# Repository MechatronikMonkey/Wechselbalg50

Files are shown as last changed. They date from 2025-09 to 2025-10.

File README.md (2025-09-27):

# Wechselbalg 50 (WB50)
Wechselbalg 50 is a 50‑watt tube guitar amplifier built entirely on a PCB. It combines classic British crunch with a modern high‑gain voice, switchable by relay. The name “Wechselbalg” (changeling) nods to the two distinct characters living in one chassis.

> Tagline (working): “Two voices, one heart of iron.”

## Highlights
- Two switchable voicings via relay (Classic ↔ Beast)
- Cascaded 12AX7 preamp with bright peakers
- Cathode follower into a classic T/M/B tone stack
 - Serial FX loop (always active; not bypassable); dual master volumes (post‑loop, RL3 selects)
- Long‑tail‑pair PI → 2× EL34 push‑pull power stage
- Classic British NFB with Presence & Thump (Resonance/Depth)
- Fixed, trimmable bias; regulated 12‑V rail (7812) for relays/loop
- Layout goals: star‑like grounding, short grid leads, disciplined heater routing, decoupled HT nodes

## Circuit overview
1) Input and V1: high‑value grid leak + grid stopper, cathode bypass options for British mid focus.  
2) Voicing section: relay switches additional gain/treble‑peaking networks for the Beast mode.  
3) Cathode follower → passive T/M/B tone stack for low‑impedance drive.  
4) FX loop: buffered send/return; always in circuit (no bypass); two post‑loop master volumes (Rhythm/Lead) with relay selection.  
5) Phase inverter: long‑tail‑pair (12AX7) with balanced plate loads.  
6) Power stage: 2× EL34 fixed‑bias push‑pull; screen resistors; coupling caps per side.  
7) Feedback shaping: Presence and Resonance inside the negative feedback leg from the output transformer secondary.  
8) Power supply: bridge rectifier, choke‑assisted filtering and stepped B+ distribution; regulated 12 V for control circuitry.

## Channel switching and controls
- Channel toggle (front) or footswitch (“SW.” jack) drives a common control line that actuates multiple relays:
	- RL1: preamp voicing (Plexi ↔ BE)
	- RL2: gain pot routing (Gain 1 ↔ Gain 2)
	- RL3: master selection (Volume 1 ↔ Volume 2, both post‑loop)
- The “SW.” jack is a latching footswitch input (no audio). With a plug inserted, the footswitch takes over; without it, the front‑panel CHANNEL mini‑toggle controls the state.
- Result: two distinct channels with their own Gain and Master settings while keeping the FX loop operating at a stable level.
 - Rear control: Thump (Resonance/Depth) shapes low‑frequency feedback for tighter vs. bigger low‑end feel.

## Safety
This project involves lethal voltages up to ~500 V. Only qualified persons should build or service it. Always discharge filter caps, use an isolation transformer, work one‑handed where possible, and wear eye protection.

## Scope & status
This repository aims at a reproducible PCB implementation of a classic small‑box‑style topology (without using protected brand names).  
Planned artifacts: schematic capture, PCB layout, BOM, bring‑up checklist and measurement notes.

## Naming
“Wechselbalg” = changeling/shapeshifter – a subtle hint at the two switchable voices. Short code: WB50.

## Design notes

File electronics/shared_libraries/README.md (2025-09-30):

# Gemeinsame Bibliotheken für Wechselbalg50

Dieser Ordner enthält gemeinsame Bibliotheken für die Projekte im Wechselbalg50-Repository.

## Struktur

- `symbols/`: Enthält Symbol-Bibliotheken (.kicad_sym)
- `footprints/`: Enthält Footprint-Bibliotheken (.pretty)
- `3dmodels/`: Enthält 3D-Modelle für die Footprints

## Verwendung

Die Projekte im Repository sind bereits so konfiguriert, dass sie auf diese gemeinsamen Bibliotheken zugreifen.
Die Pfade in den Bibliothekstabellen (`sym-lib-table` und `fp-lib-table`) verwenden den relativen Pfad `${KIPRJMOD}/../shared_libraries/...`.

## Hinzufügen neuer Symbole/Footprints

Wenn du neue Symbole oder Footprints erstellen möchtest, die in mehreren Projekten verwendet werden sollen:

1. Öffne KiCad und den Symbol- oder Footprint-Editor
2. Stelle sicher, dass du auf die gemeinsame Bibliothek als aktive Bibliothek eingestellt hast
3. Erstelle dein neues Symbol/Footprint und speichere es in der gemeinsamen Bibliothek
4. Es wird dann automatisch in allen Projekten verfügbar sein, die auf die gemeinsame Bibliothek verweisen

## 3D-Modelle

Für 3D-Modelle sollte der Pfad in den Footprint-Eigenschaften entsprechend angepasst werden. 
Verwende `${KIPRJMOD}/../shared_libraries/3dmodels/...` anstelle von lokalen Pfaden.

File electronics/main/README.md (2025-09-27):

# WB50 KiCad Projektstruktur

Dieses Verzeichnis enthält das komplette KiCad-Projekt inkl. lokaler Bibliotheken, Teilschaltpläne, PCB-Hilfsdateien und Fertigungs-/Montageordner.

## Struktur
- libraries/
  - symbols/: Projekt‑Symbolbibliothek `wb50_symbols.kicad_sym`
  - footprints/: Projekt‑Footprints in `wb50_footprints.pretty/`
  - 3dmodels/: 3D‑Modelle (optional)
- schematics/: Teilschaltpläne, die später als Hierarchieblätter in `wb50.kicad_sch` eingebunden werden
- pcb/: DXF‑Hilfsdateien (Board‑Outline, Keepouts, Front/Rear‑Panel‑Guides)
- fabrication/: Gerber/Bohrdaten, Fab‑Notizen, Stückliste und Pick&Place
- simulation/spice/: SPICE‑Testbench und Model‑Hinweise

## Erste Schritte (Front‑/Rear‑Panel zuerst)
1) Symbole & Footprints erstellen/zuweisen
   - Externe Bedienelemente (Potenziometer, Schalter, Klinken, Netz‑/Standby‑Schalter, LED) als Symbole in `wb50_symbols.kicad_sym` pflegen.
   - Passende Footprints in `wb50_footprints.pretty/` ablegen oder Standardbibliotheken verwenden.
2) Teilschaltpläne befüllen
   - In `schematics/` liegen Platzhalter für Preamp, Voicing‑Relays, Tone‑Stack, FX‑Loop, Masters, PI, Power‑Amp, NFB‑Shaping, Power‑Supply, Control‑Power.
   - Externe Bedienelemente zunächst sauber im Schaltplan anlegen (mit eindeutigen Referenzen und Netz‑Namen).
3) PCB‑Vormontage der Front/Rear‑Elemente
   - Im PCB‑Editor die Footprints der externen Bedienelemente zuerst entsprechend der Front/Rear‑Panel‑Mechanik platzieren.
   - DXF‑Hilfsgeometrie in `pcb/` importieren (Panel‑Bohrungen/Abstände), um Positionen zu verifizieren.
4) Verdrahtung/Netze nachziehen
   - Danach restliche Baugruppen platzieren, sensible Netze kurz halten (Grids, CF→Tonestack), sternförmige Masseführung beachten.

Tipp: In der `sym-lib-table` und `fp-lib-table` sind die lokalen Bibliotheken bereits auf `${KIPRJMOD}` referenziert.

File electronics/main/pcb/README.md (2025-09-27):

DXF‑Hilfsdateien (Board‑Outline, Keepouts, Panel‑Bohrungen) können hier abgelegt und in den PCB‑Editor importiert werden.

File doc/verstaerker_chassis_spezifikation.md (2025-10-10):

# Verstärker-Chassis Wechselbalg50 - Spezifikation

## Bestellung
**Datum**: 10. Oktober 2025
**Lieferant**: Tube-Town
**Artikel**: TTC Headshell British #15 - Open Frame
**Art.Nr.**: ttc-hd-br15
**Lieferzeit**: ca. 12-15 Wochen

## Abmessungen
- **A (Breite)**: 550 mm
- **B (Höhe)**: 220 mm  
- **C (Tiefe)**: 240 mm
- **Gewicht**: 8 kg
- **Konstruktion**: Open Frame (offen für optimale Belüftung)

## Materialien und Ausstattung

### Oberflächenfinish
- **Tolex**: [to-tt-ivo] Tube-Town Elfenbein / Ivory
- **Zierpiping**: Gold (abgestimmt auf Lautsprecherbox-Keder)

### Mechanische Ausstattung
- **Ecken**: [pe-c1824k] Metallecken schwarz 2-schenkelig
- **Griff**: [fe099-0943] Fender® Vintage Dogbone schwarz

## Design-Koordination

### **Perfektes Matching mit Lautsprecherbox:**
```
                   VERSTÄRKER         LAUTSPRECHERBOX
Abmessungen:       550x220x240mm      550x500x260mm
Tolex:             Ivory              Ivory            ✅
Ecken:             Schwarz 2-schenkelig Schwarz 2-schenkelig ✅  
Griff:             Fender Dogbone      Fender Dogbone   ✅
Akzente:           Gold Piping         Gold Keder       ✅
```

### **Stapelbare Konfiguration:**
- **Identische Breite**: 550mm - perfekt stapelbar
- **Harmonische Proportionen**: Head/Cabinet Verhältnis ~1:2,3
- **Einheitliches Design**: Komplettes Ivory/Schwarz/Gold Schema

## Technische Eigenschaften
- **Open Frame Konstruktion**: Optimale Wärmeableitung für Röhren
- **British Style**: Klassisches Marshall-inspiriertes Design
- **Robuste Bauweise**: Metallecken für Touring-Tauglichkeit
- **Kompakte Abmessungen**: Transportfreundlich bei voller Funktionalität

## Elektronik-Kompatibilität
**Ausgelegt für**:
- 50W Röhrenverstärker
- EL34 Push-Pull Endstufe
- 2x 12AX7 Vorstufe
- Transformatoren bis 3kg (Power + Output)
- Hammond 193H Drossel

## Kosten
- **Warenwert**: 300,79 €
- **Versand**: 8,45 €
- **MwSt**: 49,37 €
- **Gesamtsumme**: 309,24 €

## Notizen
- Professionelle TTC Fertigung (12-15 Wochen)
- Perfekt abgestimmt auf TTC 1x12" Lautsprecherbox
- Hochwertige Materialien im vintage Fender-Stil
- Open Frame für optimale Röhren-Kühlung
- Komplettes Set mit einheitlichem Design-Schema

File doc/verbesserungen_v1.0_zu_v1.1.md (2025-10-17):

# Verbesserungen von Version 1.0 zu Version 1.1

**Datum:** 15. Oktober 2025

## Übersicht
Dieses Dokument beschreibt die notwendigen Verbesserungen und Änderungen zwischen Version 1.0 und Version 1.1 des Wechselbalg50 Röhrenverstärkers.

---

## 1. Kathoden-Heizung Spannungsdifferenz

### Problem
Die Spannungsdifferenz zwischen Kathode und Heizung darf gemäß Röhrenspezifikation maximal 100V betragen. Bei der aktuellen Schaltung V1.0 besteht die Gefahr, dass die Kathode der Tone-Stack-Vorstufe auf ca. 160V ansteigt, was die zulässige Differenz überschreitet.

### Geplante Maßnahmen

#### 1.1 Überprüfung aller Kathodenspannungen
- [ ] Messung aller Kathodenspannungen im Betrieb
- [ ] Dokumentation der gemessenen Werte
- [ ] Vergleich mit zulässigen Maximalwerten der verwendeten Röhren
- [ ] Besondere Aufmerksamkeit auf Tone-Stack-Vorstufe

#### 1.2 Heater Voltage Elevation (falls erforderlich)
**Bedingung:** Wenn Kathodenspannung > 90V

**Maßnahme:** Heizspannungsanhebung um 75V

- [ ] Implementierung einer Heater Voltage Elevation Schaltung
- [ ] Anhebung der Heizspannung um 75V
- [ ] Neuberechnung der Kathode-Heizung-Differenz
- [ ] Verifizierung: Differenz < 100V
- [ ] Anpassung des Schaltplans (Schematic Update)
- [ ] Update der PCB-Layout falls erforderlich

#### 1.3 Umstellung auf 5V Relais-Steuerung (falls 1.2 implementiert wird)
**Bedingung:** Wenn Heater Voltage Elevation implementiert wird

**Hintergrund:** Durch die Heizspannungsanhebung wird eine separate 5V Versorgung für die Relais-Steuerung erforderlich.

**Maßnahme:** Implementierung 5V Versorgung und Umstellung auf 5V Relais

- [ ] Recherche und Auswahl geeigneter 5V Relais für Kanalumschaltung
- [ ] 5V Wicklung vom Transformator nutzen (falls vorhanden) oder separate Lösung
- [ ] Brückengleichrichter für 5V AC Wicklung
- [ ] LDO Spannungsregler für 5,0V Regulierung (analog zur 12V Versorgung)
- [ ] Schaltplan Update: 5V Versorgungssektion
- [ ] Schaltplan Update: Relais-Ansteuerung auf 5V umstellen
- [ ] PCB Update: 5V Relais Footprints
- [ ] BOM Update: 5V Relais, LDO für 5V, Brückengleichrichter

### Erwartetes Ergebnis
- Kathodenspannung Tone-Stack: ~160V (gemessen)
- Heizspannung (elevated): +75V
- Resultierende Differenz: ~85V ✓ (< 100V Limit)

---

## 2. Thermisches Management / PCB-Layout

### Problem
Die Wärmeentwicklung der Röhren kann zu erhöhten Temperaturen auf der PCB führen, was die Lebensdauer und Zuverlässigkeit der Bauteile beeinträchtigen kann.

### Geplante Maßnahmen

#### 2.1 Temperaturmessung und Analyse
- [ ] Temperaturmessung auf der PCB im Betrieb (verschiedene Lastbedingungen)
- [ ] Identifikation von Hotspots
- [ ] Messung der Bauteiltemperaturen in Röhrennähe
- [ ] Dokumentation der Temperaturen (Idle, Normal, Vollast)
- [ ] Vergleich mit maximalen Betriebstemperaturen der Bauteile

#### 2.2 PCB-Layout Optimierung (falls erforderlich)
**Bedingung:** Wenn Bauteiltemperaturen kritische Werte erreichen

**Maßnahme:** Vergrößerung des Abstands zwischen Röhrensockeln und temperaturkritischen Bauteilen

- [ ] Analyse: Welche Bauteile sind besonders temperaturempfindlich?
- [ ] PCB-Layout Revision: Bauteile weiter von Röhrensockeln positionieren
- [ ] Berücksichtigung thermischer Konvektion (heiße Luft steigt auf)
- [ ] Ggf. Verwendung von Bauteilen mit höherer Temperaturklasse
- [ ] Ggf. zusätzliche Kühlung/Belüftung in Betracht ziehen
- [ ] PCB Update für Version 1.1
- [ ] Prototyp-Test mit Temperaturmessung zur Validierung

### Erwartetes Ergebnis
- Alle Bauteile arbeiten innerhalb ihrer spezifizierten Temperaturbereiche
- Erhöhte Zuverlässigkeit und Lebensdauer
- Reduziertes Risiko von thermisch bedingten Ausfällen

---

## Weitere geplante Verbesserungen
_(Hier können weitere Punkte ergänzt werden)_

---

## Status
- **Version 1.0:** Aktuell in Entwicklung
- **Version 1.1:** Geplant
- **Hauptgrund für Update:** Einhaltung Kathode-Heizung Spannungsdifferenz

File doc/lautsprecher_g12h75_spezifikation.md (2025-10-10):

# Lautsprecher-Spezifikation: Celestion G12H-75 Creamback

## Produktdetails
**Hersteller**: Celestion
**Modell**: G12H-75 Creamback
**Impedanz**: 8Ω
**Datum**: 10. Oktober 2025

## Technische Daten
- **Belastbarkeit**: 75W RMS
- **Impedanz**: 8Ω
- **Magnet**: Keramik
- **Durchmesser**: 12" (305mm)
- **Resonanzfrequenz**: ~75Hz
- **Frequenzgang**: 70Hz - 5kHz
- **Empfindlichkeit**: ~96dB

## Sound-Charakteristik

### **Frequenzverhalten:**
- **Bass**: Straff und kontrolliert
- **Mitten**: Sehr präsent und aggressiv (2-4kHz Peak)
- **Höhen**: Scharf und durchsetzungsfähig
- **Breakup**: Musikalisch bei höheren Pegeln

### **Klangcharakter:**
- Klassischer 70er Hard Rock Sound
- Aggressive, schneidende Mitten
- Perfekt für Marshall JCM800/Plexi Style
- Hervorragende Durchsetzungsfähigkeit
- Modern verbesserte Version der Heritage Serie

## Kompatibilität mit Wechselbalg50

### **Perfektes Matching:**
```
Verstärker: 50W EL34 Push-Pull
Lautsprecher: 75W Belastbarkeit
Sicherheitsfaktor: 1,5x ✅

8Ω Impedanz:
- Optimale Anpassung für NFB-Umschaltung
- Straffe Bassansprache
- Moderne Charakteristik
```

### **Sound-Modi Kompatibilität:**
```
Classic Mode (weniger NFB):
- Warmer, vintage Marshall Sound
- Natürliches Röhren-Breakup
- Musikalische Kompression

Beast Mode (mehr NFB):  
- Aggressive, schneidende Mitten
- Straffe, kontrollierte Bässe
- Modern High-Gain Character
```

## Gehäuse-Integration

### **TTC 1x12" Box (550x500x260mm):**
- **Montage**: Standard 12" Ausschnitt (310mm)
- **Tiefe**: Ausreichend Platz (260mm Gehäuse)
- **Dämpfung**: Empfohlene Innenauskleidung mit 25mm PU-Schaum
- **Port**: Geschlossen oder Flex-Back je nach gewünschtem Sound

## Kostenaufstellung
- **Lautsprecher**: ~165€ (geschätzt)
- **Versand**: ~10-15€
- **Gesamtkosten**: ~175-180€

## Bezugsquellen (Empfehlung)
1. **Thomann**: Zuverlässig, guter Service
2. **Music Store**: Oft günstige Preise
3. **Amazon**: Schnelle Lieferung
4. **Tube-Town**: Passend zu restlicher Bestellung

## Sound-Erwartung

### **Perfekt für:**
- Hard Rock / Classic Rock
- Marshall-Style Crunch Sounds  
- Aggressive Lead-Sounds
- Durchsetzungsfähige Rhythmus-Gitarre

### **Weniger geeignet für:**
- Sehr cleane Jazz-Sounds
- Extreme High-Gain Metal (dafür ist er aber zu vintage)
- Sehr warme, runde Sounds (dafür G12M-65 wählen)

## Fazit
Der G12H-75 Creamback 8Ω ist die perfekte Ergänzung zum Wechselbalg50. Die Kombination aus klassischem 70er Marshall Character und modernen Verbesserungen macht ihn ideal für die zwei Persönlichkeiten (Classic ↔ Beast) des Verstärkers.

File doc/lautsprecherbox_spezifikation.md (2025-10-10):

# Lautsprecherbox Wechselbalg50 - Spezifikation

## Bestellung
**Datum**: 10. Oktober 2025
**Lieferant**: Tube-Town
**Artikel**: TTC 1X American Custom Shop
**Art.Nr.**: ttc-1XAM
**Lieferzeit**: ca. 12-15 Wochen

## Abmessungen
- **A (Breite)**: 550 mm
- **B (Höhe)**: 500 mm  
- **C (Tiefe)**: 260 mm
- **Gewicht**: 25 kg
- **Konfiguration**: 1x12" Lautsprecher

## Materialien und Ausstattung

### Oberflächenfinish
- **Tolex**: [to-tt-ivo] Tube-Town Elfenbein / Ivory
- **Bespannung**: [gc-ma-651] British schwarz, FRET00026
- **Keder**: Dick Gold, 4.8 x 9.1 mm

### Mechanische Ausstattung
- **Rückwand**: Flex Back / 3-geteilte Rückwand (abnehmbar für Sound-Variation)
- **Ecken**: [pe-c1819k] Fender® Stil schwarz, 2-schenkelig
- **Griff**: [fe099-0943] Fender® Vintage Dogbone schwarz
- **Front**: XL Front, schräge Schallwand
- **TT Logo**: kein Logo
- **Kabelsatz**: ohne Kabelsatz (wird separat beschafft)
- **Griffschale seitlich**: Nein
- **Steckrollen**: Nein

## Technische Eigenschaften
- **Innenvolumen**: ~53 Liter (geschlossen)
- **Konstruktion**: Geschlossen mit abnehmbarer 3-geteilter Rückwand
- **Sound-Charakteristik**: 
  - Geschlossen: Straffer, präziser Bass
  - Teilweise/ganz offen: Luftiger, vintage Sound
- **Kompatibilität**: Optimiert für 50W Röhrenverstärker mit EL34 Endstufe

## Geplanter Lautsprecher
**Lautsprecher**: Celestion G12H-75 Creamback 8Ω
- **Leistung**: 75W RMS (ausreichend für 50W Verstärker)
- **Impedanz**: 8Ω (optimiert für NFB-Umschaltung)
- **Charakteristik**: Aggressive Mitten, durchsetzungsfähig, perfekt für Marshall-Style
- **Sound**: Klassischer 70er Hard Rock Character mit modernen Verbesserungen

## Kosten
- **Warenwert**: 394,79 €
- **Versand**: 23,80 €
- **MwSt**: 66,83 €
- **Gesamtsumme**: 418,59 €

## Notizen
- Professionelle Fertigung durch Tube-Town
- Hochwertige Materialien im Fender-Stil
- Flexible Rückwand ermöglicht Sound-Anpassung
- Perfekt abgestimmt auf den Wechselbalg50 Röhrenverstärker
- Kompakte Abmessungen bei optimaler Klangqualität

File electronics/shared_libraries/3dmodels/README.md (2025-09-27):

3D‑Modelle (STEP/VRML) für Visualisierung und Mechanik‑Checks.

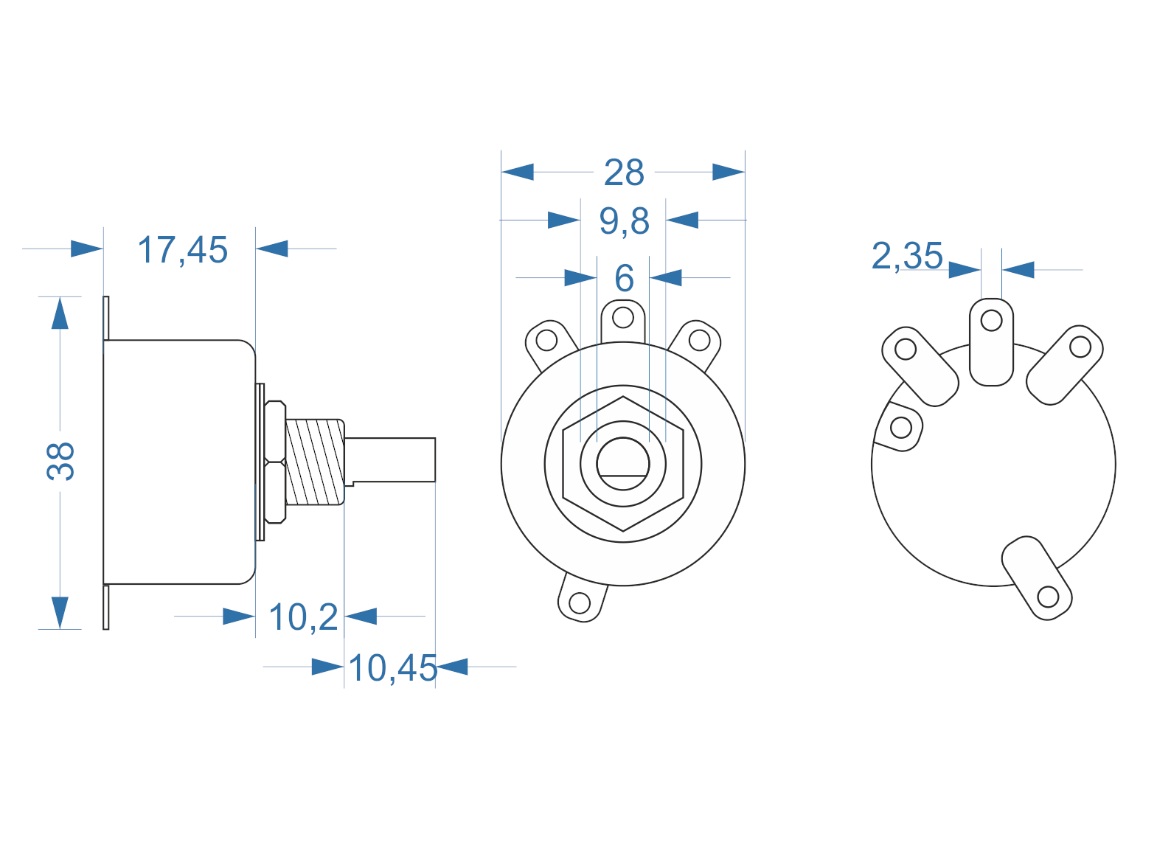
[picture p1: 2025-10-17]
doc/datasheets/imedanceSelector.png

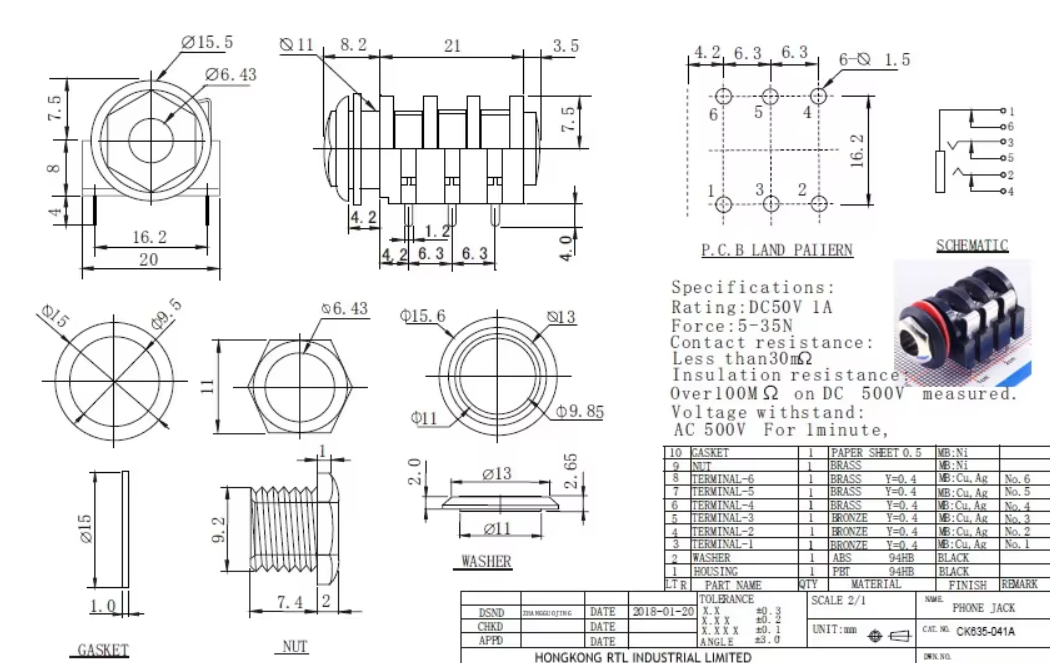
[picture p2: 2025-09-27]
doc/datasheets/trs_jack_6_35mm_dimensions.png

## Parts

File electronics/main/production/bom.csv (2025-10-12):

Designator | Footprint | Quantity | Value | LCSC Part #
AC-IN1, AC-IN2, AC-IN3, AC-IN4, AC-IN5, AUDIO-A1, AUDIO-B1, AUDIO-FROM-FX1, AUDIO-FROM-FX2, AUDIO-TO-FX1, AUDIO-TO-FX2, GND-AUD1, HV-B1, HV-OT1, HV-OT2, THUMP1, THUMP2 | TestPoint_THTPad_D3.0mm_Drill1.5mm | 17 | 1
AC-IN6, AC-IN7, AC-IN8 | TestPoint_THTPad_D4.0mm_Drill2.0mm | 3 | 1
AIR1, AIR10, AIR11, AIR12, AIR13, AIR14, AIR15, AIR16, AIR17, AIR18, AIR19, AIR2, AIR20, AIR21, AIR22, AIR3, AIR4, AIR5, AIR6, AIR7, AIR8, AIR9 | MountingHole_4.3mm_M4 | 22 | VentingHole
BIASA1, BIASB1, GND-MESS1 | TestPoint_Pad_D2.0mm | 3 | 1
C1 | CAP-TH_BD5.0-P2.00-D0.8-FD | 1 | 33uF 50V | C89792
C10, C8, C9 | CAP-TH_BD12.5-P5.00-D0.6-FD | 3 | 33uF 500V 5R5-ESR | C443401
C11, C12, C15 | CAP-TH_BD10.0-P5.00-D1.0-FD | 3 | 18uF 450V ±20% | C781269
C13, C14 | CAP-TH_BD6.3-P2.50-D1.0-FD | 2 | 10uf/100V | C2029
C2 | CAP-TH_BD16.0-P7.50-D1.2-FD | 1 | LKMI2501C682MF | C442803
C3, C4 | C0805 | 2 | CC0805KRX7R9BB104 | C49678
C5, C6 | CAP-TH_BD6.3-P2.50-D1.0-FD | 2 | 0,82uF 400V 20 % | C2029
C7 | CAP-TH_BD16.0-P7.50-D1.2-FD | 1 | 22uF_450V_16*20 | C10737
CHOKE1, CHOKE2 | TestPoint_THTPad_D2.5mm_Drill1.2mm | 2 | 1
D1, D2, D3, D4, D5, D6 | DO-41_BD2.4-L4.7-P8.70-D0.9-RD | 6 | UF4007_C960666 | C960666
J1 | WB50_Jack_TRS_6pin_16.2mm | 1 | IN
J2 | WB50_Jack_TRS_6pin_16.2mm | 1 | SW
J3 | WB50_Jack_TRS_6pin_16.2mm | 1 | OUT1
J4 | WB50_Jack_TRS_6pin_16.2mm | 1 | OUT2
J5 | WB50_Jack_TRS_6pin_16.2mm | 1 | Send
J6 | WB50_Jack_TRS_6pin_16.2mm | 1 | Return
MH3, MH4, MH5, MH6, MH7, MH8 | MountingHole_3.5mm_Pad_TopBottom | 6 | MountHole
N1, N2 | NetTie_0.5mm_2Pad | 2 | ~
R1, R15, R6 | RES-TH_BD3.0-L9.5-P13.50-D0.6 | 3 | 33k 500V 2W | C70845
R10, R11, R35, R36 | RES-TH_BD2.7-L6.2-P10.20-D0.4 | 4 | CR1/2WS-470K±5%-ST52 | C2857409
R12, R14, R20, R3, R5, R9 | RES-TH_BD4.5-L11.0-P15.00-D0.7 | 6 | CR1W-100K±5%-TT63 | C601829
R13 | RES-TH_BD4.0-L10.5-P14.50-D0.6 | 1 | 820R 350V 500mW | C167619
R16, R38, R42, R7 | RES-TH_BD4.5-L11.0-P15.00-D0.7 | 4 | CR1W-10M±5%-6T63 | C2897121
R17, R18, R2, R33 | RES-TH_BD2.4-L6.3-P10.30-D0.6 | 4 | 1Meg 500V 250mW | C1370556
R19, R25, R26, R27, R34 | RES-TH_BD5.5-L15.0-P19.00-D0.8 | 5 | CF3WS-10KΩ±5%_T | C120810
R21, R28 | RES-TH_BD2.7-L6.2-P10.20-D0.4 | 2 | CR1/4W-47K±5%-ST52 | C2896823
R22, R23 | RES-TH_BD2.4-L6.3-P10.30-D0.6 | 2 | CFR-25JT-52-1K5 | C1370569
R24 | RES-TH_BD6.0-L17.5-P21.50-D0.8 | 1 | MOF5WS-47Ω±5% | C121969
R29 | RES-TH_BD2.7-L6.2-P10.20-D0.4 | 1 | CR1/4W-15K±5%-OT52 | C2894565
R30, R31 | RES-TH_BD2.7-L6.2-P10.20-D0.4 | 2 | MF1/4W-1Ω±1%-ST26 | C2903254
R32, R39, R40, R44, U22, U27, U28, U4 | RES-TH_BD3.5-L9.0-P13.00-D0.5 | 8 | CR1/2W-220K±5%-XT52 | C2894491
R37 | RES-TH_BD2.3-L6.5-P10.50-D0.5 | 1 | CF1/4W-1_5KΩ±5%_T52 | C120059
R4, R8 | RES-TH_BD2.7-L6.2-P10.20-D0.4 | 2 | CR1/4W-2K7±5%-ST26 | C2894624
R41, R43 | RES-TH_BD5.5-L15.0-P19.00-D0.8 | 2 | CF2W-2200Ω±5%_T | C187501
RELAY1, RELAY2, RELAY3 | RELAY-TH_G5V-1 | 3 | G5V-1-12V | C31113
RV1 | WB50_Pot_Omeg_PC20BU_P5.00mm | 1 | Presence
RV10 | WB50_Pot_Omeg_PC20BU_P5.00mm | 1 | Return
RV2 | WB50_Pot_Omeg_PC20BU_P5.00mm | 1 | Bass
RV3 | WB50_Pot_Omeg_PC20BU_P5.00mm | 1 | Mid
RV4 | WB50_Pot_Omeg_PC20BU_P5.00mm | 1 | Treble
RV5 | WB50_Pot_Omeg_PC20BU_P5.00mm | 1 | Vol1
RV6 | WB50_Pot_Omeg_PC20BU_P5.00mm | 1 | Vol2
RV7 | WB50_Pot_Omeg_PC20BU_P5.00mm | 1 | Gain1
RV8 | WB50_Pot_Omeg_PC20BU_P5.00mm | 1 | Gain2
RV9 | WB50_Pot_Omeg_PC20BU_P5.00mm | 1 | Send
U1 | HEATSINK-TH_XSD366-094 | 1 | XSD366-094 | C286227
U10 | MICA_CAP_L15.5_W3.6_P8.7 | 1 | 250pF 500V 5%
U11, U12, U13, U16, U38, U6, U9 | MICA_CAP_L15.5_W3.6_P8.7 | 7 | 500pF 500V 5%
U14, U15, U17, U25, U26 | MUSTARD_CAP_D8.5_L20.5_P25.5 | 5 | 22n 630V 5%
U18 | RES-TH_BD5.0-L15.5-P19.50-D0.7 | 1 | 470R 500V 2W | C2905226
U19, U23, U41 | MUSTARD_CAP_D10_L32_P40.4 | 3 | 100n 630V 5%
U2 | TO-220-3_L10.0-W4.5-P2.54-L | 1 | L7812CV-DG | C2914
U20 | RES-TH_BD4.0-L11.5-P15.50-D0.7 | 1 | CF2WS-82KΩ±5%_T | C120647
U21 | MICA_CAP_L15.5_W3.6_P8.7 | 1 | 100pF 500V 5%
U24, U7 | MUSTARD_CAP_D8.5_L20.5_P25.5 | 2 | 4n7 630V 5%
U29, U30 | RES-TH_BD9.5-L22.0-P26.00-D0.7 | 2 | CR-L5W-1KΩJ | C334294
U3 | ABS-SMD_L5.0-W4.4-P4.00-LS7.0-BL | 1 | AB24S | C882375
U31 | FUSE-TH_L22.5-W10.8-P22.50_0031.8201.G | 1 | 16A 20mm 500V 5mm Plugin Fuse | C3204125
U32 | RES-TH_BD5.0-L15.5-P19.50-D0.7 | 1 | CR2W-4K7±5%-9T73 | C2903451
U33 | RES-ADJ-SMD_3314G-1-103E | 1 | 3314G-1-503E | C719184
U34 | SW-TH_ST-0-102-C03-N003-RS | 1 | ST-0-102-C03-N003-RS | C1788489
U35 | SW-TH_MT-0-102-C004-N004-RS | 1 | MT-0-103-C004-N004-RS | C22448931
U36 | MUSTARD_CAP_D8.5_L20.5_P25.5 | 1 | 47n 630V 5%
U37 | MUSTARD_CAP_D10_L32_P40.4 | 1 | 470n 630V 5%
U39 | MUSTARD_CAP_D10_L32_P40.4 | 1 | 220n 630V 5%
U40 | CAP-TH_BD4.0-P1.50-D0.5-FD | 1 | KM1H_4u7_M0405 | C2873979
U5 | RES-TH_BD5.0-L15.5-P19.50-D0.7 | 1 | CR2W-68K±5%-9T73 | C2903458
U8 | MUSTARD_CAP_D8.5_L20.5_P25.5 | 1 | 2n2 630V 5%
V1, V2, V3, V6 | WB50_Socket_Noval_9Pin_D21.0mm_Hole1.8mm | 4 | 12AX7
V4, V5 | WB50_Socket_Octal_8Pin_D26.0mm_Hole2.0mm | 2 | EL34
X12 | TestPoint_THTPad_D4.0mm_Drill2.0mm | 1 | GND_OT
X9 | TestPoint_THTPad_D4.0mm_Drill2.0mm | 1 | Audio IN

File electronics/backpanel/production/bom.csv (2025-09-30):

Designator | Footprint | Quantity | Value | LCSC Part #
J1, J2 | WB50_Jack_TRS_6pin_16.2mm | 2 | Audio Jack TRS, 6pin (with switches)
X1 | TestPoint_THTPad_D4.0mm_Drill2.0mm | 1 | Audio IN
X2 | TestPoint_THTPad_D4.0mm_Drill2.0mm | 1 | GND_OT
X3 | TestPoint_THTPad_D1.5mm_Drill0.7mm | 1 | NFB
X4 | TestPoint_THTPad_D4.0mm_Drill2.0mm | 1 | GND_NFB

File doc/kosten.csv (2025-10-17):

Datum | Kategorie | Artikel | Lieferant | Stückzahl | Einzelpreis_EUR | Summe_EUR | Notizen
2025-09-27 | Bedienelemente | Potentiometer-Kappen | AliExpress | 1 | 4,85 | 4,85 | Erste Ausgabe
2025-09-27 | Schutzausrüstung | CO2-Laser Schutzbrille | AliExpress | 1 | 19,59 | 19,59
2025-09-27 | Anschlüsse | TRS-Buchsen 6,35 mm | AliExpress | 1 | 11,68 | 11,68
2025-09-27 | Anzeige | LED-Indicator | AliExpress | 1 | 5,13 | 5,13
2025-09-29 | Röhren | JJ EL34 Version II - Paar | Tube-Town | 1 | 48,00 | 48,00 | jjel34-II-pair
2025-09-29 | Röhren | Tung-Sol 12AX7 / ECC83 Reissue | Tube-Town | 2 | 23,90 | 47,80 | ts12ax7
2025-09-29 | Trafos | TT Übertrager 50 Watt für Marshall / JCM800 / Plexi | Tube-Town | 1 | 98,00 | 98,00 | tt-otMAJ50
2025-09-29 | Trafos | TT Netztransformator 50 Watt für Marshall / JCM 800 / Plexi | Tube-Town | 1 | 119,00 | 119,00 | tt-maj50-pw
2025-09-29 | Drosseln | Hammond Drossel 193H | Tube-Town | 1 | 57,70 | 57,70 | ha193h
2025-09-29 | Sockel | Sockel Oktal Keramik Print - GOLD, 2er Packung | Tube-Town | 1 | 3,40 | 3,40 | sk26
2025-09-29 | Sockel | Sockel Noval Keramik Print, Gold, 2er Satz | Tube-Town | 1 | 4,65 | 4,65 | sk13
2025-09-29 | Versand | Versand (Deutsche Post Paket: 9,1471 kg | Regellaufzeit: 3 Werktage) | Tube-Town | 1 | 10,50 | 10,50
2025-09-29 | Befestigung | Spring Tube Retainer (EL34, E34L, 6L6GC-STR, KT77 etc.) with damping ring | Tube Amp Doctor | 2 | 2,28 | 4,56 | TR | TAD-140707
2025-09-29 | Befestigung | EL84 / 6BQ5 Tube Retainer | Tube Amp Doctor | 2 | 1,75 | 3,50 | TR-84 | TAD-140707
2025-09-29 | Befestigung | Tube Retainer (small bottle 6L6WGC, 5881, GZ34 u.ä) | Tube Amp Doctor | 2 | 1,75 | 3,50 | TR-M | TAD-140707
2025-09-29 | Versand | Versand Tube Amp Doctor (Bestellung 140707) | Tube Amp Doctor | 1 | 6,50 | 6,50
2025-10-05 | PCB-Komponenten | Elektronische Bauteile für PCB | LCSC Parts | 1 | 40,00 | 40,00
2025-10-10 | Lautsprecherbox | TTC 1X American Custom Shop (1x12) | Tube-Town | 1 | 394,79 | 394,79 | ttc-1XAM
2025-10-10 | Versand | Versand Tube-Town (Lautsprecherbox) | Tube-Town | 1 | 23,80 | 23,80
2025-10-10 | Verstärker-Chassis | TTC Headshell British #15 - Open Frame | Tube-Town | 1 | 300,79 | 300,79 | ttc-hd-br15
2025-10-10 | Versand | Versand Tube-Town (Verstärker-Chassis) | Tube-Town | 1 | 8,45 | 8,45
2025-10-10 | Lautsprecher | Celestion G12H-75 Creamback 8 Ohm | Online-Händler | 1 | 165,00 | 165,00 | Geschätzte Kosten
2025-10-10 | Fußschalter | Lead Foot FS-1 Fußpedal | Online-Händler | 1 | 9,90 | 9,90 | Kanalumschaltung
2025-10-14 | Sensoren | Hall-Stromsensor QNHC3 | AliExpress | 1 | 15,25 | 15,25 | Ausgang 2,5 ± 2 V / 1,65 ± 0,625 V | Eingang 6 A
2025-10-14 | PCB-Komponenten | Verschiedene Diskrete Bauteile | LCSC | 1 | 85,00 | 85,00
2025-10-17 | Röhren | Verschiedene Röhren zum Testen | Tube Amp Doctor | 1 | 249,31 | 249,31 | TAD EL34 Blackplate, JJ ECC823, JJ ECC81, MICA Kondensatoren
2025-10-17 | Elektronik | C14 Kabel, Nixie Buchsen, Mustard Caps | Digikey | 1 | 125,37 | 125,37 | Netzkabel, Anschlussbuchsen, Coupling Kondensatoren
2025-10-17 | PCB-Komponenten | Potentiometer, Sicherungen, Widerstände | Reichelt | 1 | 85,65 | 85,65 | Bedienelemente und passive Bauteile
2025-10-17 | Sockel | Impedanzwahlschalter, Röhrensockel | Tube-Town | 1 | 24,10 | 24,10 | Lautsprecher-Impedanzschalter und zusätzliche Sockel
2025-10-17 | ZWISCHENSUMME | Kosten bis 17.10.2025 |  |  |  |  |  |  | 2057,27 | Gesamtkosten aller bisherigen Bestellungen

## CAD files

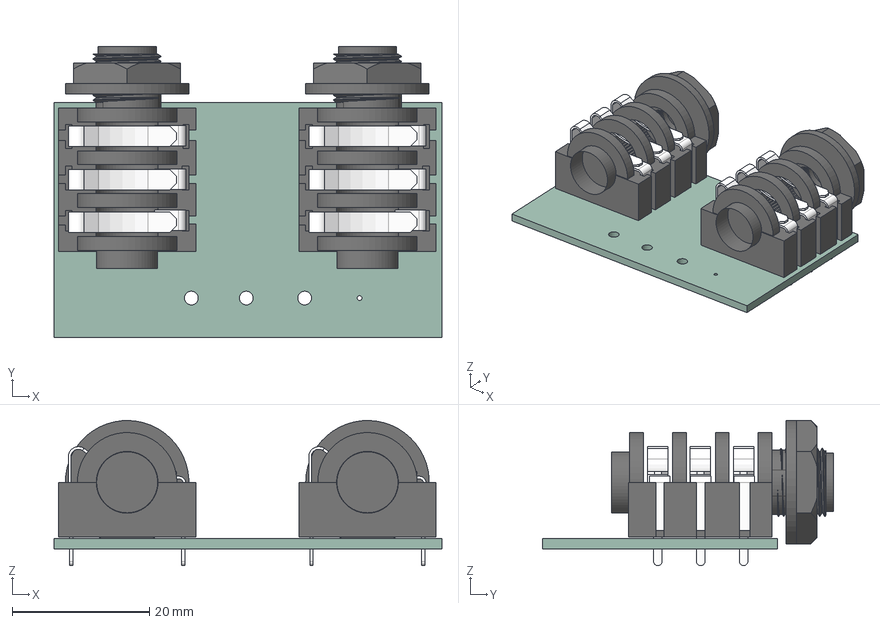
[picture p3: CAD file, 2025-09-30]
electronics/backpanel/wb50_back.step
56.5 x 42.4 x 21.1 mm
JackConnector-female-6.35-entrance-threaded v1 x 2
nut v4 x 2
wb50_back_PCB

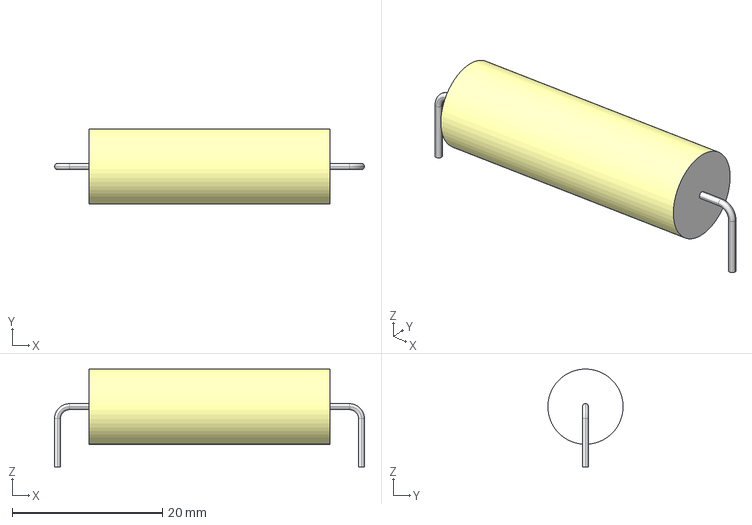
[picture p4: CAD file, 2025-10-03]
electronics/shared_libraries/3dmodels/AXIAL_CYLINDRICAL_FILM_CAPACITOR_D10_L32_Pitch40.4_PinD0.8.step
41.2 x 10.00 x 13.0 mm

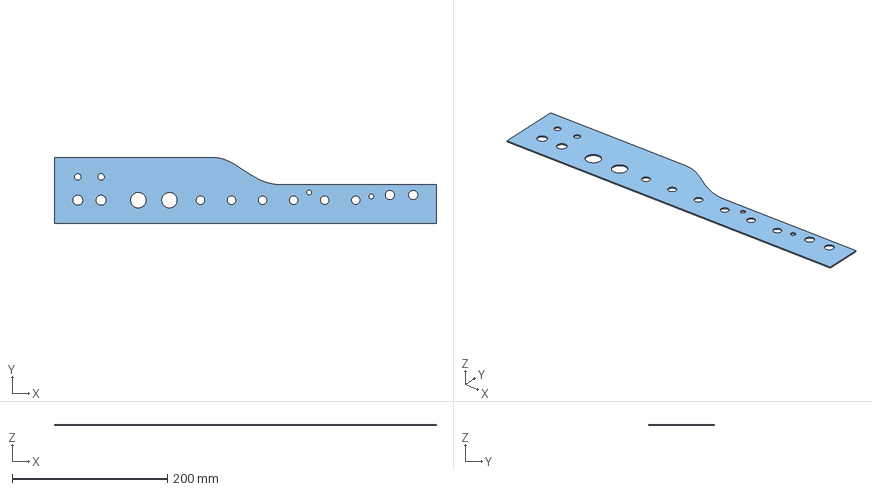
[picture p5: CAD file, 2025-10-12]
mechanics/frontPlate3DV2.FCStd
492.0 x 85.0 x 1.50 mm
ShapeString
ShapeString001
ShapeString002
ShapeString003
ShapeString004
ShapeString005
ShapeString006
ShapeString007
ShapeString008
ShapeString009
ShapeString010
ShapeString011
ShapeString012
ShapeString013
ShapeString015
ShapeString016
ShapeString017
ShapeString018

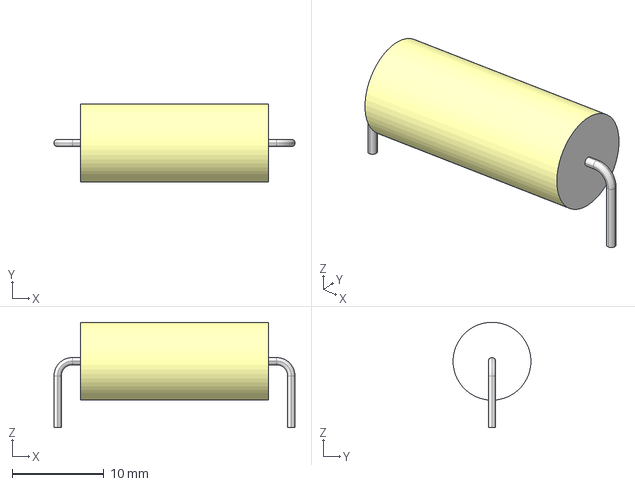
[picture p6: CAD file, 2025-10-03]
electronics/shared_libraries/3dmodels/AXIAL_CYLINDRICAL_FILM_CAPACITOR_D8.5_L20.5_Pitch25.5_PinD0.8.step
26.3 x 8.50 x 11.5 mm

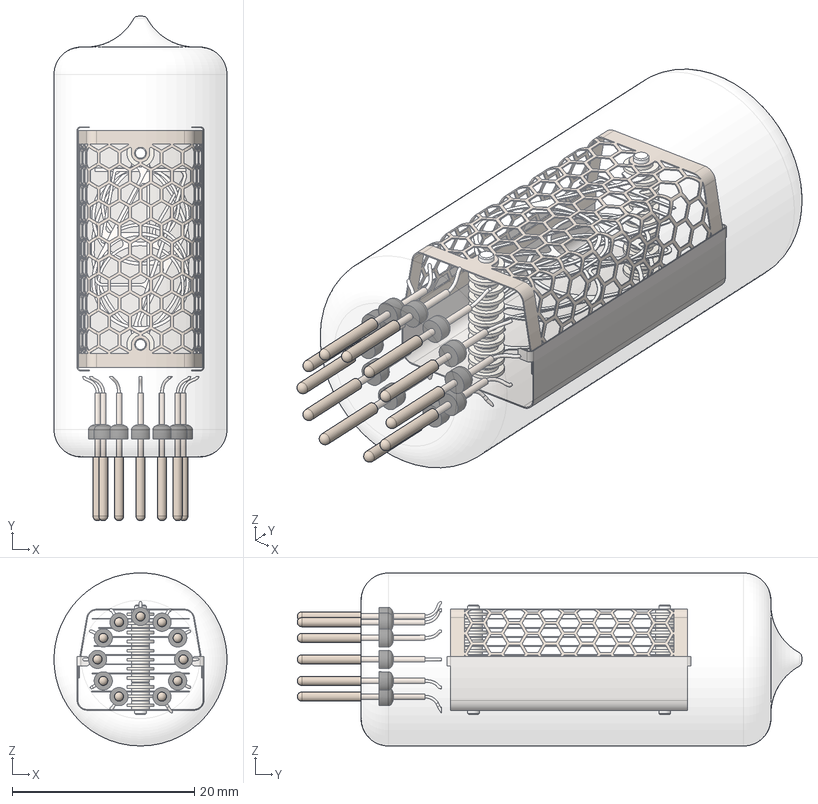
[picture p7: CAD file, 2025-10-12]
mechanics/NIXIE_TUBE.step
19.0 x 55.4 x 19.0 mm
ISOLATION x 22
NUM7
CERAMIC_ROD x 2
PIN x 11
NUM8
NUM5
ANODE_BACK
NUM3
NUM6
NUM9
PLATE
GLASS_TUBE
WIRING x 11
NUM4
NUM0
PLATE_2

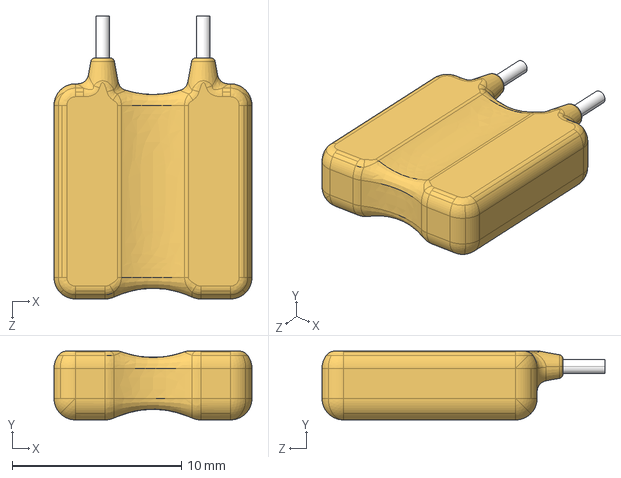
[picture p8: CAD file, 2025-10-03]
electronics/shared_libraries/3dmodels/Capacitor_Mica_CDV16.step
11.7 x 4.06 x 16.7 mm

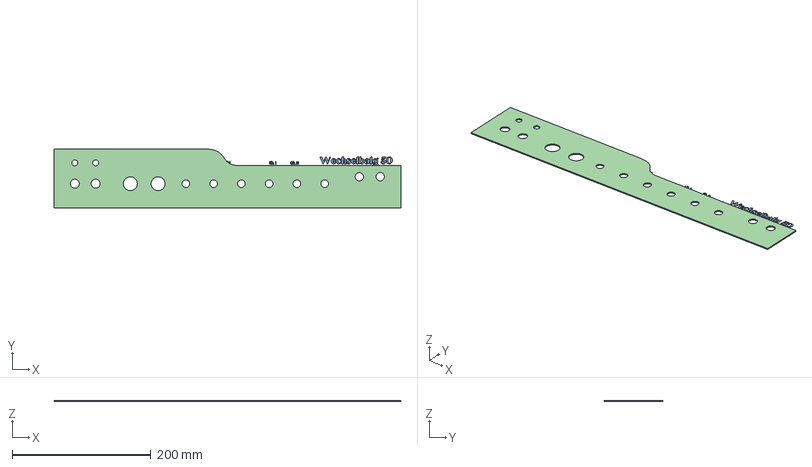
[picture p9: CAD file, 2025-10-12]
mechanics/frontPlate3D.FCStd
500.0 x 85.0 x 1.50 mm
ShapeString
ShapeString001
ShapeString002
ShapeString003
ShapeString004
ShapeString005
ShapeString006
ShapeString007
ShapeString008
ShapeString009
ShapeString010
ShapeString011
ShapeString012
ShapeString013
ShapeString014
ShapeString015
ShapeString016
ShapeString017
ShapeString018
Körper

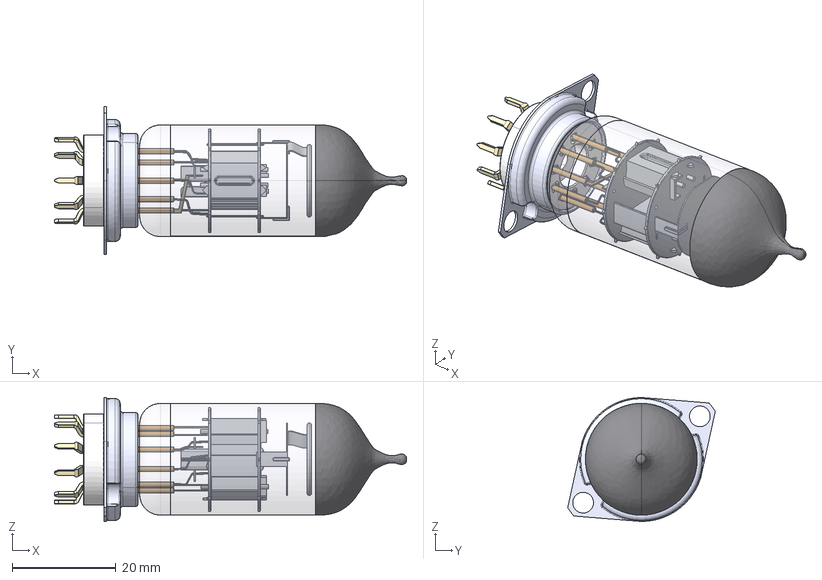
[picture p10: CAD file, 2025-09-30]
electronics/shared_libraries/3dmodels/12ax7andSocket.step
67.9 x 28.5 x 23.9 mm
socket_base x 2
parte do terminal_superior x 18
terminais_socket_9_pin x 18
suporte_socket_9_pin x 2
C寐寐硃ia de chapeu-dissipador^final x 2
suporte-dissipador x 2
dissipador x 2
cintura baixa x 4
coluna-cintura-baixa x 4
anodos x 4
anodos001 x 4
caulda da base x 2
base-vidro-corpo x 2
terminais x 18
corpo-topo x 2
terminais-internos x 6
terminais-lamina x 2
terminais-filamentos x 10
corpo-vidro-meio x 2

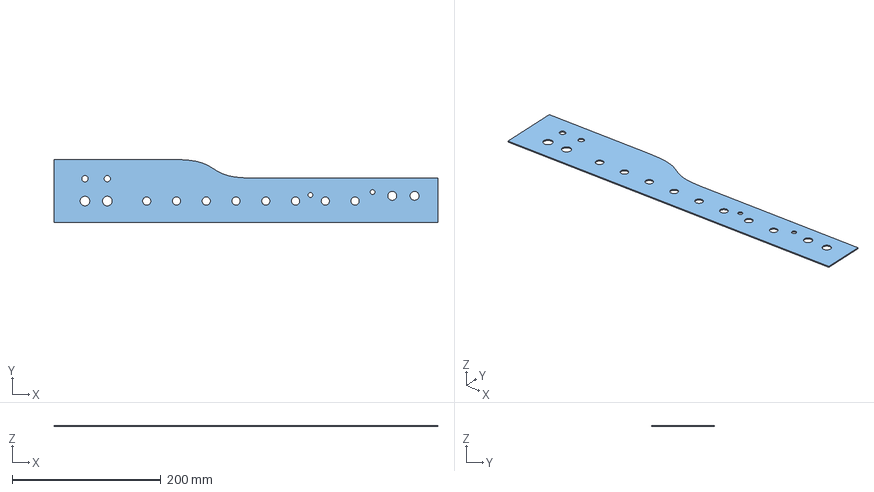
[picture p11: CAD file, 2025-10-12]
mechanics/frontPlate.FCStd
516.0 x 85.0 x 1.50 mm
ShapeString
ShapeString001
ShapeString002
ShapeString003
ShapeString004
ShapeString005
ShapeString006
ShapeString007
ShapeString008
ShapeString009
ShapeString010
ShapeString011
ShapeString012
ShapeString013
ShapeString015
ShapeString016
ShapeString017
ShapeString018
ShapeString019

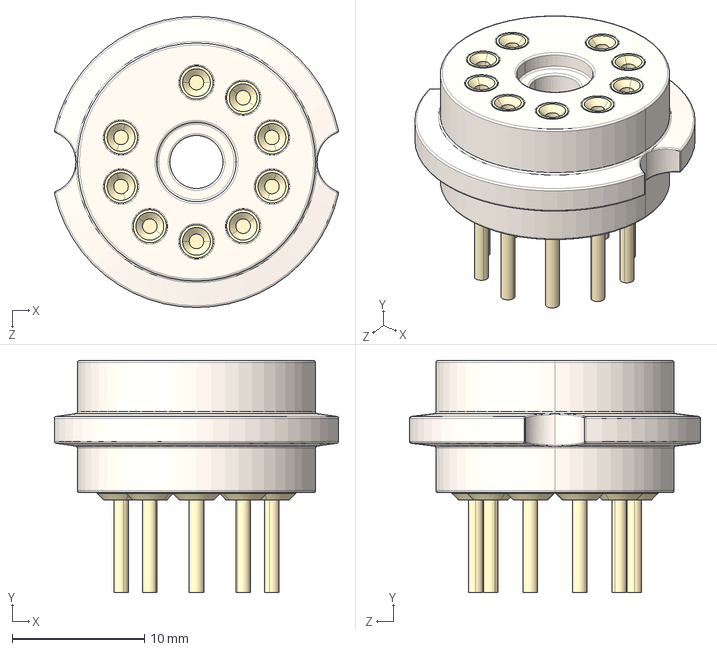
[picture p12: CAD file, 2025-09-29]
electronics/shared_libraries/3dmodels/Noval socket.STEP
21.5 x 17.6 x 22.0 mm
noval ceramic body
Noval pin x 9

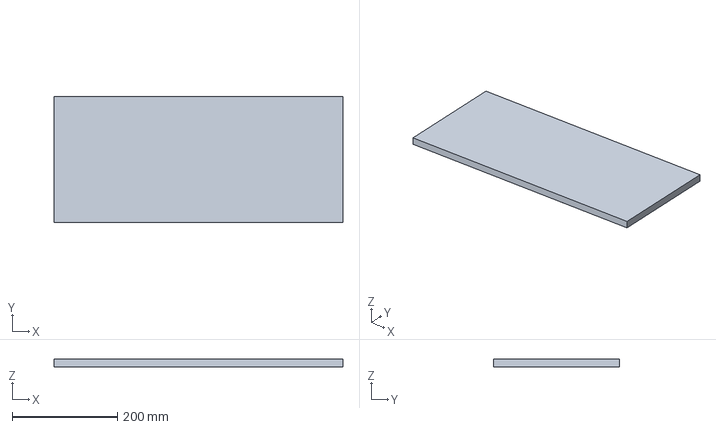
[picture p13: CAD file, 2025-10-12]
mechanics/Bodenplatte.FCStd
550.0 x 240.0 x 15.0 mm

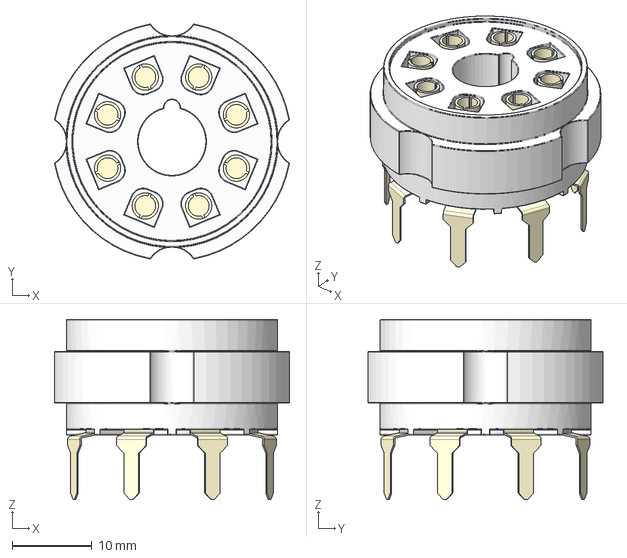
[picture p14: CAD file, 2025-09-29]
electronics/shared_libraries/3dmodels/octal-socket.stp
29.5 x 29.5 x 22.6 mm

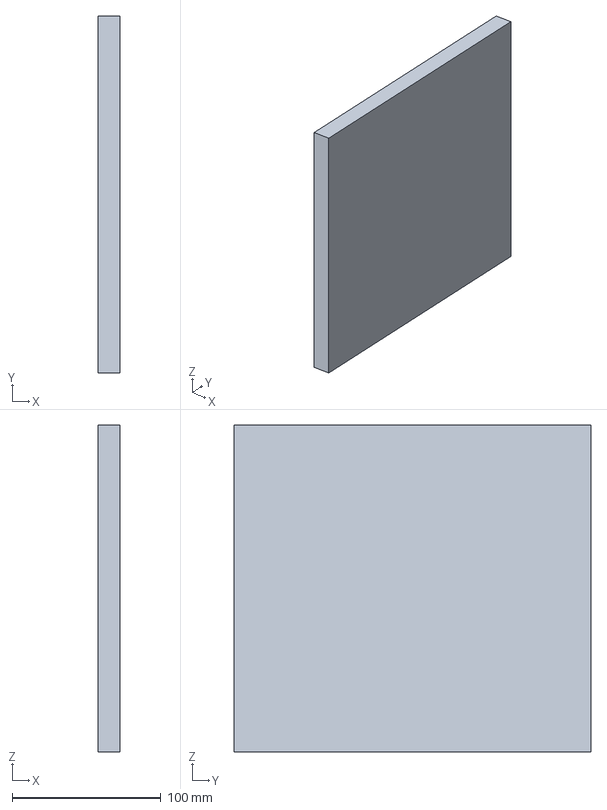
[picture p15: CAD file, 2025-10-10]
mechanics/Wand.FCStd
15.0 x 240.0 x 220.0 mm

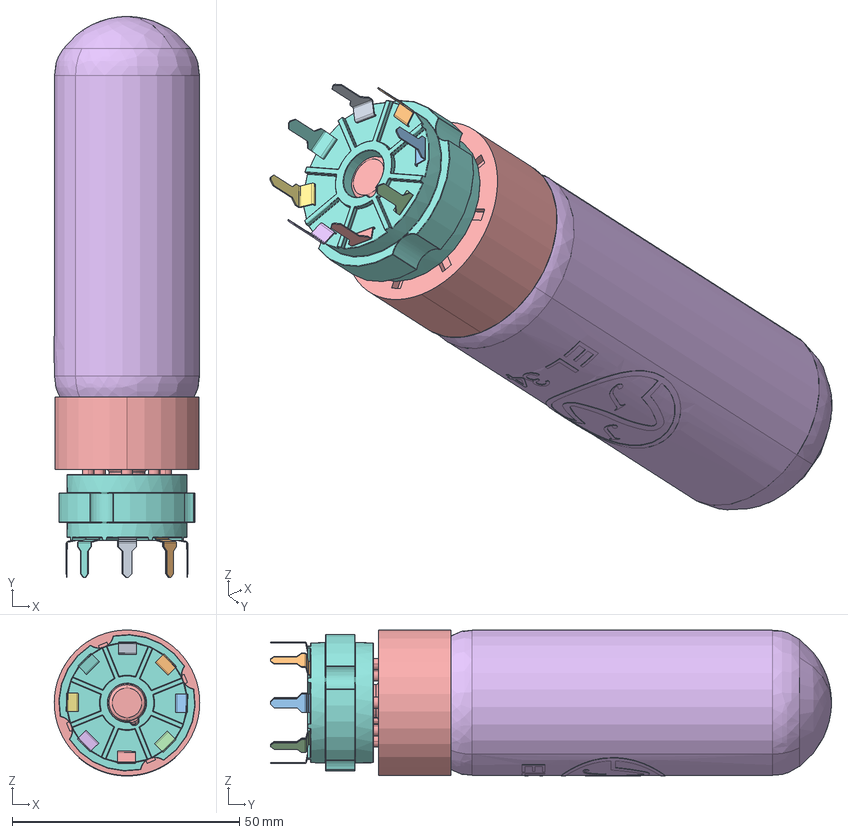
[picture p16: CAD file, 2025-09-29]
electronics/shared_libraries/3dmodels/EL34andSocket.FCStd
32.0 x 123.4 x 32.1 mm
el34_assembly
el34_assembly006
el34_assembly007
el34_assembly015
el34_assembly016
el34_assembly017
el34_assembly018
octal-socket
octal-socket001
octal-socket002
octal-socket003
octal-socket004
octal-socket005
octal-socket006
octal-socket007
octal-socket008
octal-socket009
octal-socket010
octal-socket011
octal-socket012
octal-socket013
octal-socket014
octal-socket015
octal-socket016

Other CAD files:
mechanics/Shild.step
electronics/shared_libraries/3dmodels/12ax7.STEP
mechanics/Ubertrager.FCStd
electronics/shared_libraries/3dmodels/ACJS-PH v28.step
electronics/shared_libraries/3dmodels/12ax7andSocket.FCStd
electronics/shared_libraries/3dmodels/PC20BU.stp
mechanics/Drossel.FCStd
mechanics/Transformer.FCStd
mechanics/frontPlate.dxf

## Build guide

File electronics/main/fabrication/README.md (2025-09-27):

Ablage für Fertigungsdaten:
- gerbers/ Gerber‑Lagen
- drills/ Bohrdaten (Excellon)
- fab_notes/ Hinweise für Leiterplattenhersteller
- assembly/ Stückliste (BOM) und Pick&Place

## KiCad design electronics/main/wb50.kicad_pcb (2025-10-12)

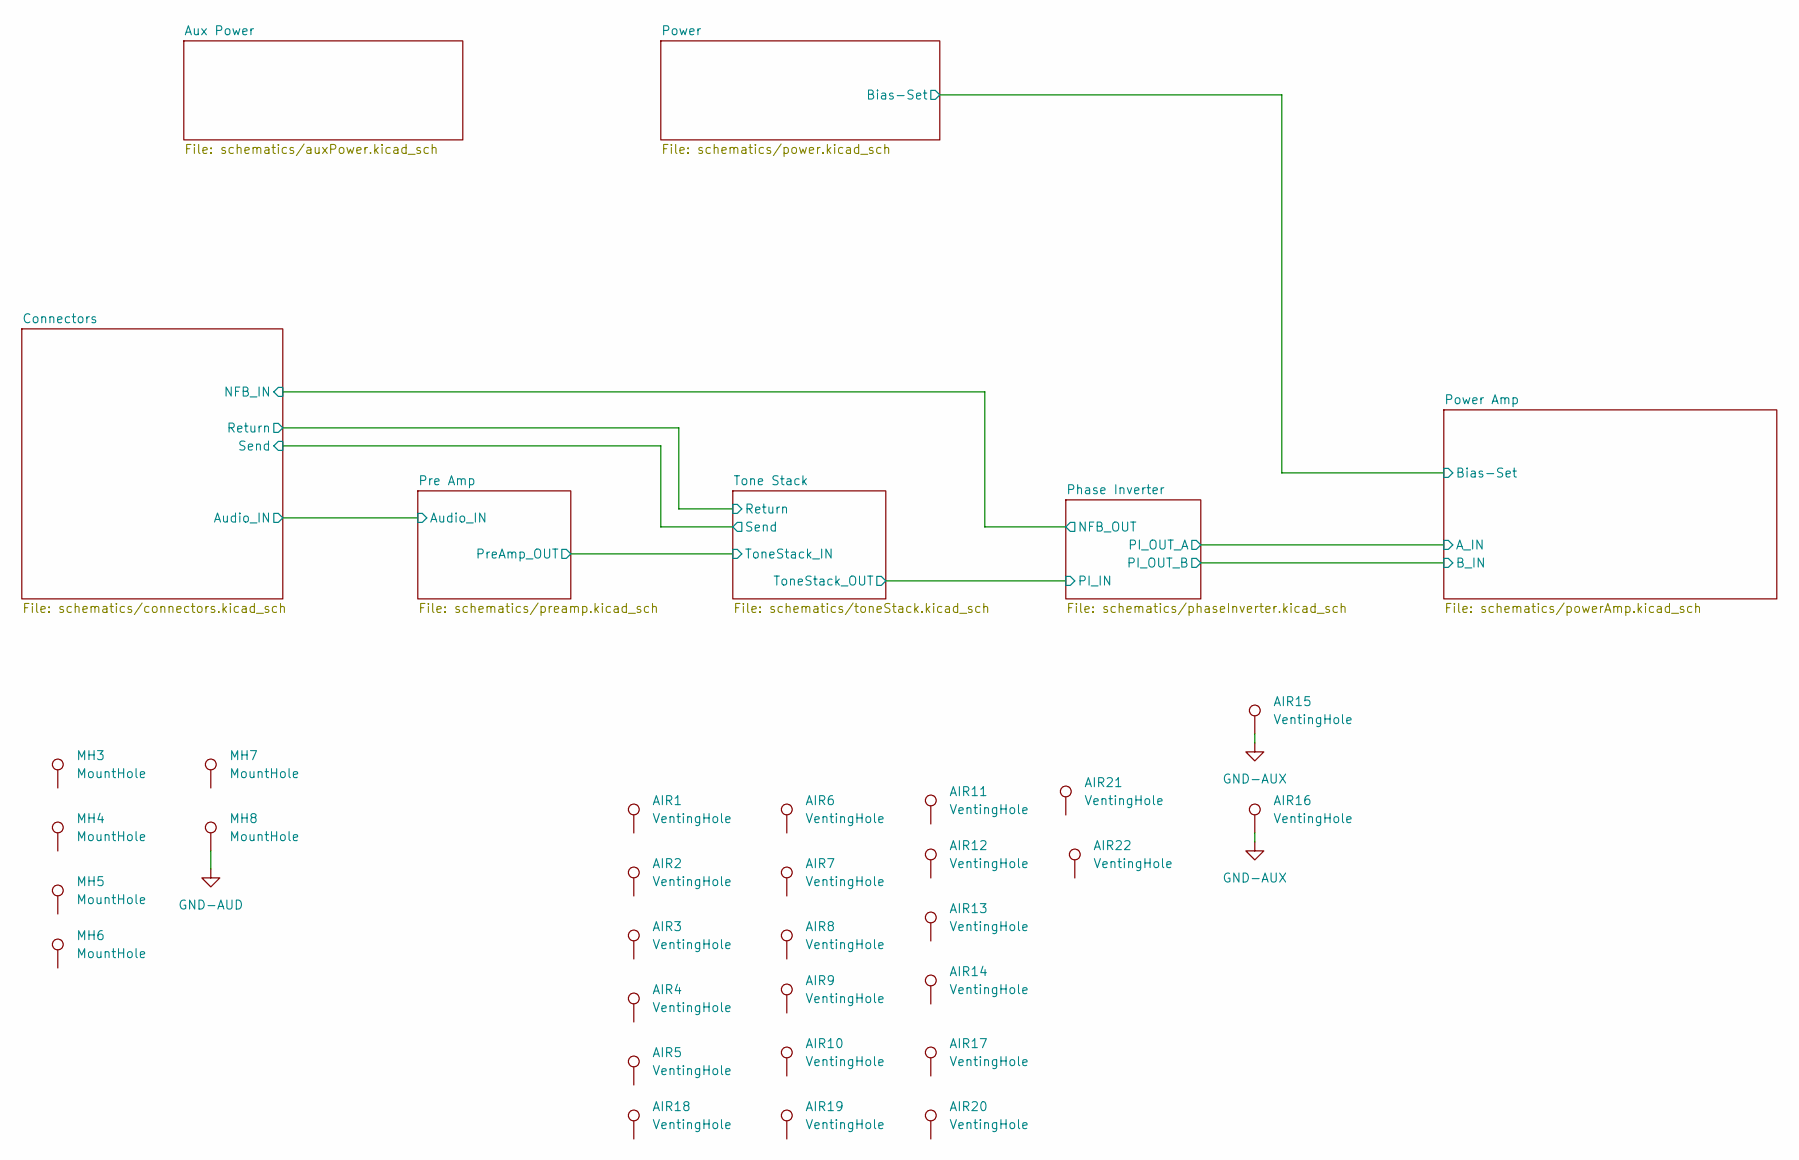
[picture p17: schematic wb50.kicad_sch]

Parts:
AIR1, AIR2, AIR3, AIR4, AIR5, AIR6, AIR7, AIR8, AIR9, AIR10, AIR11, AIR12, AIR13, AIR14, AIR15, AIR16, AIR17, AIR18, AIR19, AIR20, AIR21, AIR22: VentingHole; MountingHole_4.3mm_M4
MH3, MH4, MH5, MH6, MH7, MH8: MountHole; MountingHole_3.5mm_Pad_TopBottom

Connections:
GND-AUD: MH8.1; also elsewhere on the board

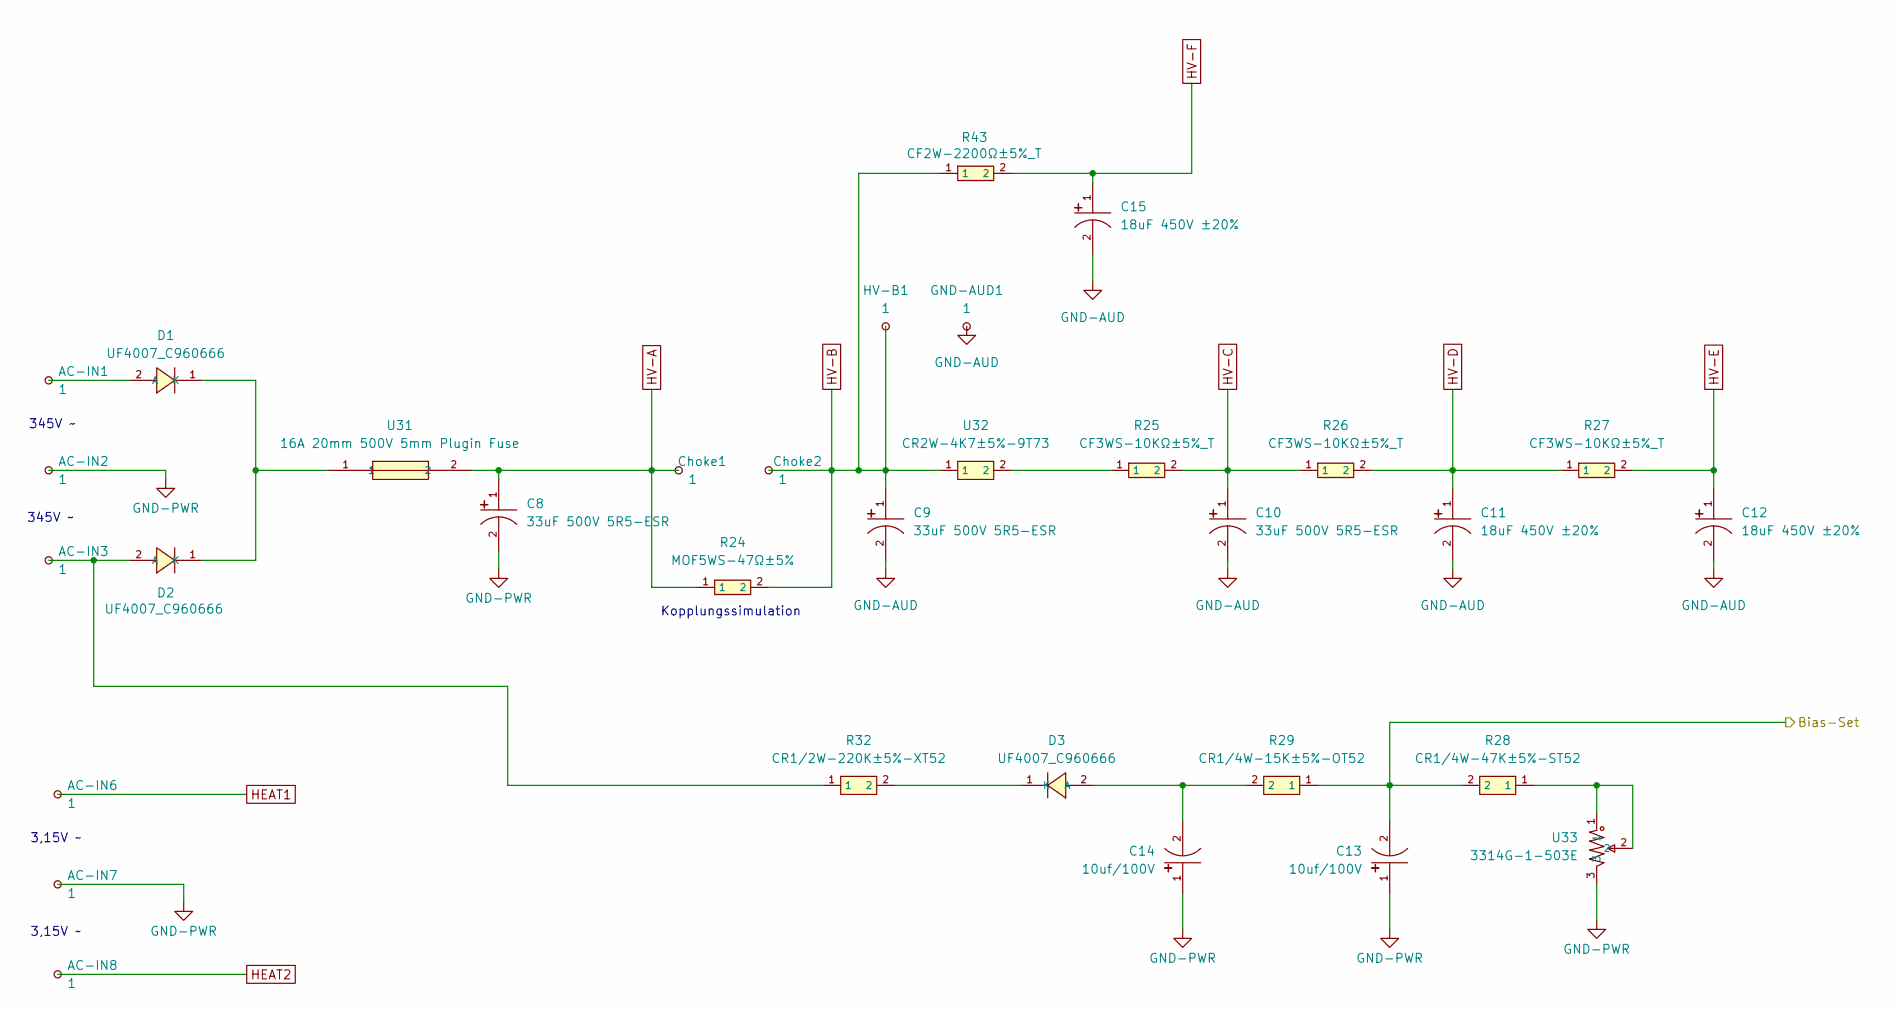
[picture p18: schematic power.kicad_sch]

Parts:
AC-IN1, AC-IN2, AC-IN3: 1; TestPoint_THTPad_D3.0mm_Drill1.5mm
AC-IN6, AC-IN7, AC-IN8: 1; TestPoint_THTPad_D4.0mm_Drill2.0mm
C8, C9, C10: 33uF 500V 5R5-ESR; CAP-TH_BD12.5-P5.00-D0.6-FD; LCSC C443401
C11, C12, C15: 18uF 450V ±20%; CAP-TH_BD10.0-P5.00-D1.0-FD; LCSC C781269
C13, C14: 10uf/100V; CAP-TH_BD6.3-P2.50-D1.0-FD; LCSC C2029
Choke1, Choke2: 1; TestPoint_THTPad_D2.5mm_Drill1.2mm
D1, D2, D3: UF4007_C960666; DO-41_BD2.4-L4.7-P8.70-D0.9-RD; LCSC C960666
GND-AUD1: 1; TestPoint_THTPad_D3.0mm_Drill1.5mm
HV-B1: 1; TestPoint_THTPad_D3.0mm_Drill1.5mm
R24: MOF5WS-47Ω±5%; RES-TH_BD6.0-L17.5-P21.50-D0.8; LCSC C121969
R25, R26, R27: CF3WS-10KΩ±5%_T; RES-TH_BD5.5-L15.0-P19.00-D0.8; LCSC C120810
R28: CR1/4W-47K±5%-ST52; RES-TH_BD2.7-L6.2-P10.20-D0.4; LCSC C2896823
R29: CR1/4W-15K±5%-OT52; RES-TH_BD2.7-L6.2-P10.20-D0.4; LCSC C2894565
R32: CR1/2W-220K±5%-XT52; RES-TH_BD3.5-L9.0-P13.00-D0.5; LCSC C2894491
R43: CF2W-2200Ω±5%_T; RES-TH_BD5.5-L15.0-P19.00-D0.8; LCSC C187501
U31: 16A 20mm 500V 5mm Plugin Fuse; FUSE-TH_L22.5-W10.8-P22.50_0031.8201.G; LCSC C3204125
U32: CR2W-4K7±5%-9T73; RES-TH_BD5.0-L15.5-P19.50-D0.7; LCSC C2903451
U33: 3314G-1-503E; RES-ADJ-SMD_3314G-1-103E; LCSC C719184

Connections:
/Power Amp/Bias-Set: C13.2, R28.2, R29.1; also elsewhere on the board
GND-AUD: C9.2, C10.2, C11.2, C12.2, C15.2, GND-AUD1.1; also elsewhere on the board
GND-PWR: AC-IN2.1, AC-IN7.1, C8.2, C13.1, C14.1, U33.3; also elsewhere on the board
HEAT1: AC-IN6.1; also elsewhere on the board
HEAT2: AC-IN8.1; also elsewhere on the board
HV-A: C8.1, Choke1.1, R24.1, U31.2; also elsewhere on the board
HV-B: C9.1, Choke2.1, HV-B1.1, R24.2, R43.1, U32.1; also elsewhere on the board
HV-C: C10.1, R25.2, R26.1; also elsewhere on the board
HV-D: C11.1, R26.2, R27.1; also elsewhere on the board
HV-E: C12.1, R27.2; also elsewhere on the board
HV-F: C15.1, R43.2; also elsewhere on the board
unnamed: AC-IN1.1, D1.2 (A)
unnamed: D1.1 (K), D2.1 (K), U31.1
unnamed: AC-IN3.1, D2.2 (A), R32.1
unnamed: C14.2, D3.2 (A), R29.2
unnamed: D3.1 (K), R32.2
unnamed: R25.1, U32.2
unnamed: R28.1, U33.1, U33.2

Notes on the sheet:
345V ~
3,15V ~
Kopplungssimulation

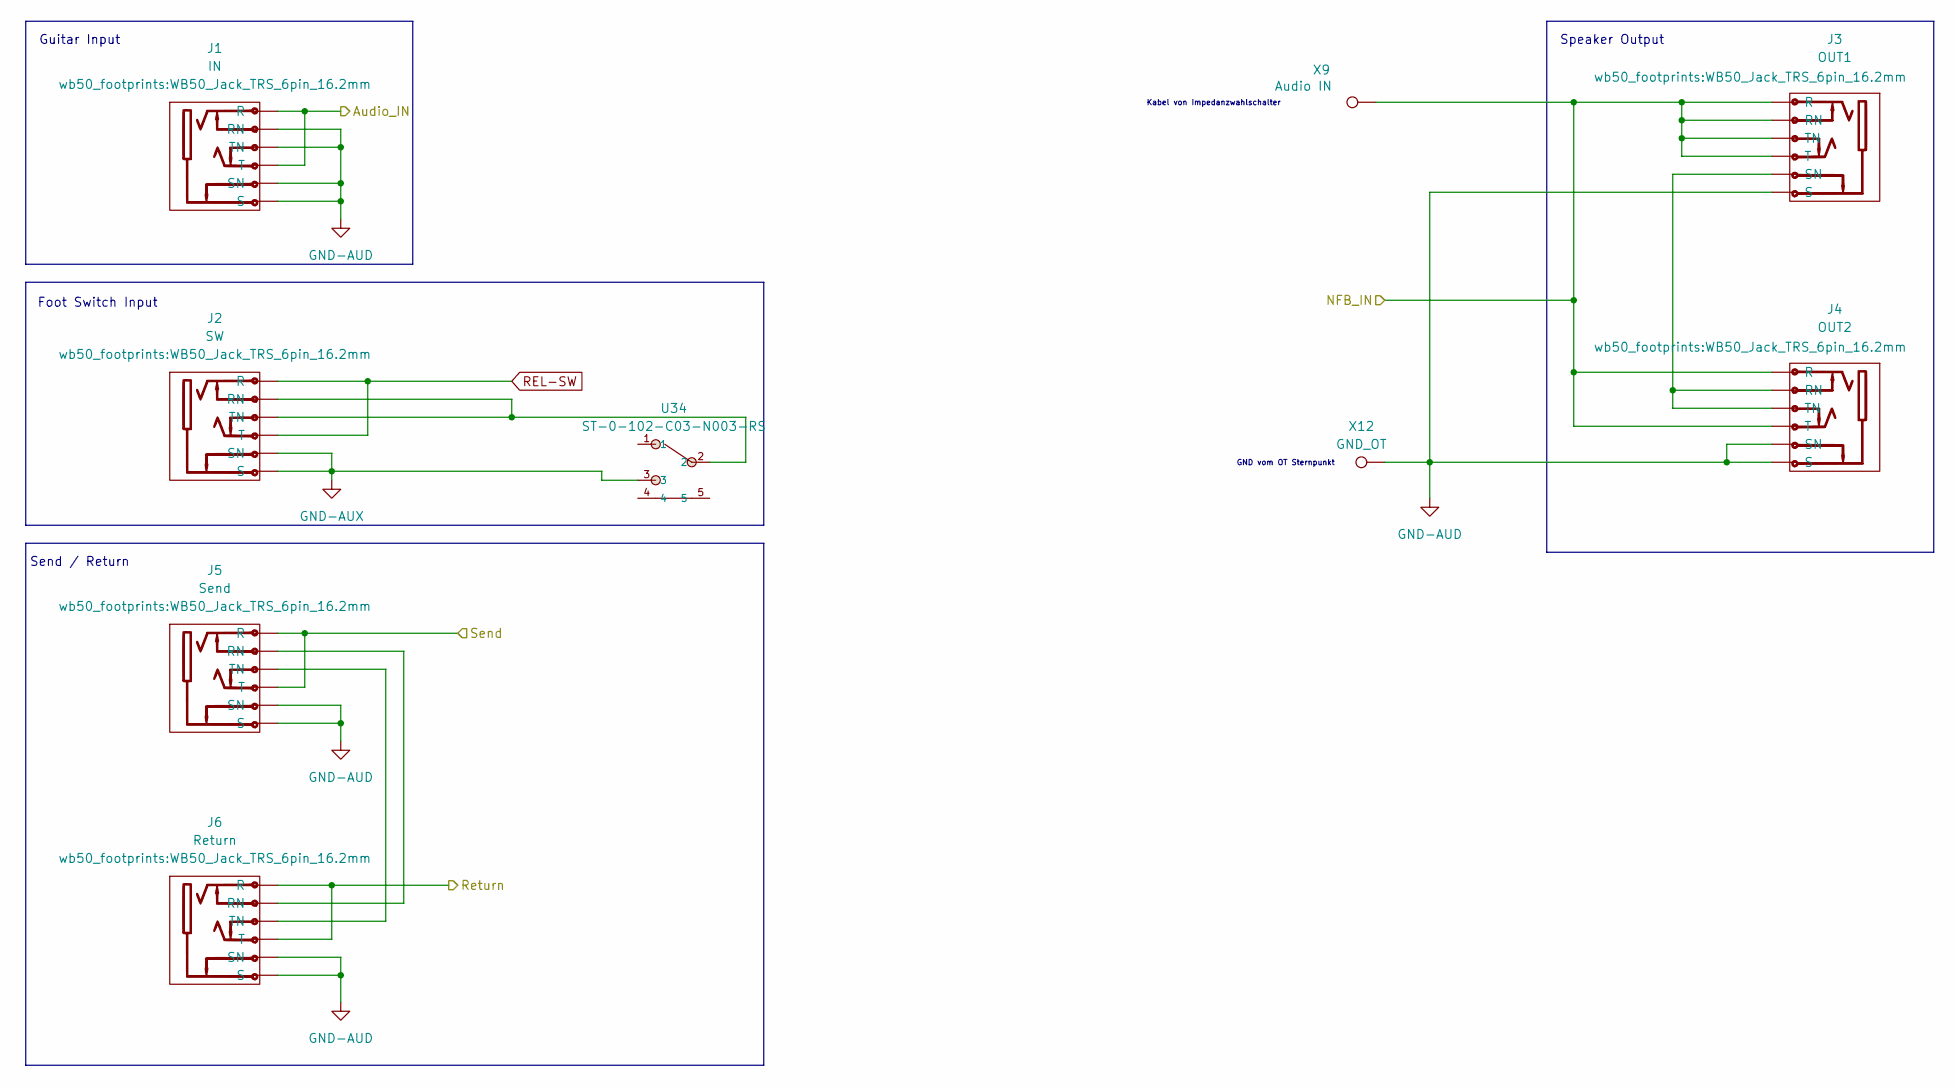
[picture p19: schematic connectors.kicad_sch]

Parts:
J1: IN; WB50_Jack_TRS_6pin_16.2mm
J2: SW; WB50_Jack_TRS_6pin_16.2mm
J3: OUT1; WB50_Jack_TRS_6pin_16.2mm
J4: OUT2; WB50_Jack_TRS_6pin_16.2mm
J5: Send; WB50_Jack_TRS_6pin_16.2mm
J6: Return; WB50_Jack_TRS_6pin_16.2mm
U34: ST-0-102-C03-N003-RS; SW-TH_ST-0-102-C03-N003-RS; LCSC C1788489
X9: Audio IN; TestPoint_THTPad_D4.0mm_Drill2.0mm
X12: GND_OT; TestPoint_THTPad_D4.0mm_Drill2.0mm

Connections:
/Connectors/Audio_IN: J1.2 (R), J1.3 (T); also elsewhere on the board
/Connectors/NFB_IN: J3.2 (R), J3.3 (T), J3.4 (TN), J3.5 (RN), J4.2 (R), J4.3 (T), X9.1; also elsewhere on the board
/Connectors/Return: J6.2 (R), J6.3 (T); also elsewhere on the board
/Connectors/Send: J5.2 (R), J5.3 (T); also elsewhere on the board
GND-AUD: J1.1 (S), J1.4 (TN), J1.5 (RN), J1.6 (SN), J3.1 (S), J4.1 (S), J4.6 (SN), J5.1 (S), J5.6 (SN), J6.1 (S), J6.6 (SN), X12.1; also elsewhere on the board
GND-AUX: J2.1 (S), J2.6 (SN), U34.3; also elsewhere on the board
unnamed: J2.4 (TN), J2.5 (RN), U34.2
unnamed: J3.6 (SN), J4.4 (TN), J4.5 (RN)
unnamed: J5.5 (RN), J6.5 (RN)
unnamed: J5.4 (TN), J6.4 (TN)
REL-SW: J2.2 (R), J2.3 (T); also elsewhere on the board

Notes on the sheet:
Foot Switch Input
Kabel von Impedanzwahlschalter
GND vom OT Sternpunkt
Guitar Input
Send / Return
Speaker Output

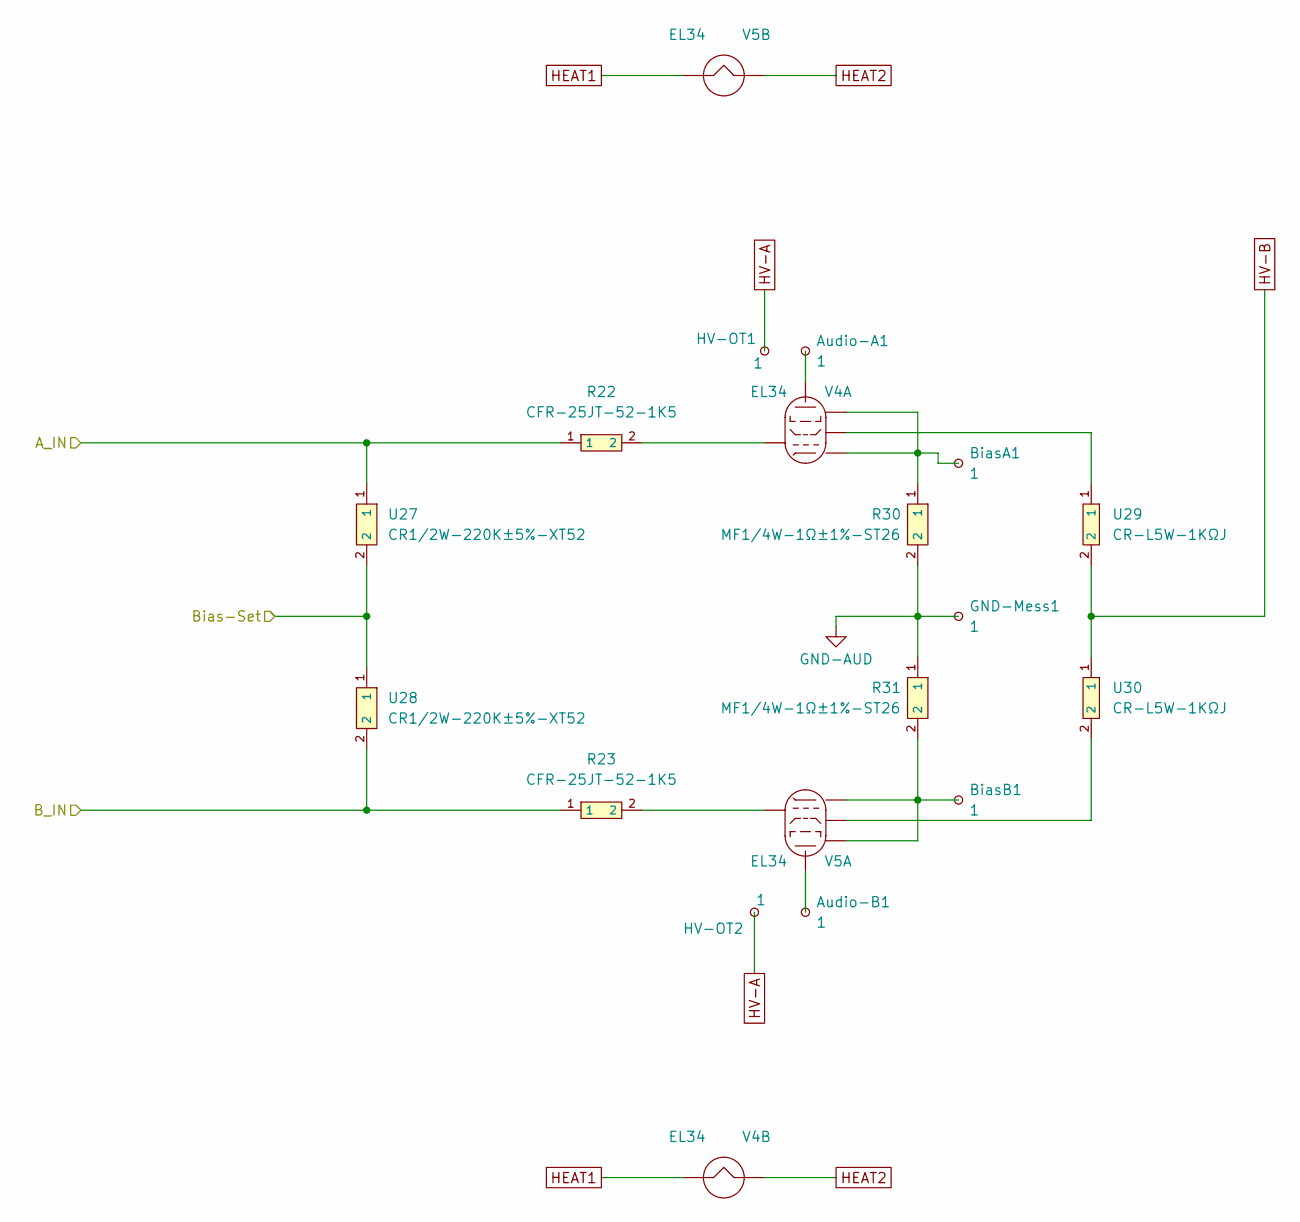
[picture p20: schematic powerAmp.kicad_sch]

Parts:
Audio-A1: 1; TestPoint_THTPad_D3.0mm_Drill1.5mm
Audio-B1: 1; TestPoint_THTPad_D3.0mm_Drill1.5mm
BiasA1: 1; TestPoint_Pad_D2.0mm
BiasB1: 1; TestPoint_Pad_D2.0mm
GND-Mess1: 1; TestPoint_Pad_D2.0mm
HV-OT1, HV-OT2: 1; TestPoint_THTPad_D3.0mm_Drill1.5mm
R22, R23: CFR-25JT-52-1K5; RES-TH_BD2.4-L6.3-P10.30-D0.6; LCSC C1370569
R30, R31: MF1/4W-1Ω±1%-ST26; RES-TH_BD2.7-L6.2-P10.20-D0.4; LCSC C2903254
U27, U28: CR1/2W-220K±5%-XT52; RES-TH_BD3.5-L9.0-P13.00-D0.5; LCSC C2894491
U29, U30: CR-L5W-1KΩJ; RES-TH_BD9.5-L22.0-P26.00-D0.7; LCSC C334294
V4, V5: EL34; WB50_Socket_Octal_8Pin_D26.0mm_Hole2.0mm

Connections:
/Phase Inverter/PI_OUT_A: R22.1, U27.1; also elsewhere on the board
/Phase Inverter/PI_OUT_B: R23.1, U28.2; also elsewhere on the board
/Power Amp/Bias-Set: U27.2, U28.1; also elsewhere on the board
GND-AUD: GND-Mess1.1, R30.2, R31.1; also elsewhere on the board
HEAT1: V4.2 (f), V5.2 (f); also elsewhere on the board
HEAT2: V4.7 (f), V5.7 (f); also elsewhere on the board
HV-A: HV-OT1.1, HV-OT2.1; also elsewhere on the board
HV-B: U29.2, U30.1; also elsewhere on the board
unnamed: Audio-A1.1, V4.3 (a)
unnamed: R22.2, V4.5 (g1)
unnamed: U29.1, V4.4 (g2)
unnamed: BiasA1.1, R30.1, V4.1 (g3), V4.8 (k)
unnamed: Audio-B1.1, V5.3 (a)
unnamed: R23.2, V5.5 (g1)
unnamed: U30.2, V5.4 (g2)
unnamed: BiasB1.1, R31.2, V5.1 (g3), V5.8 (k)

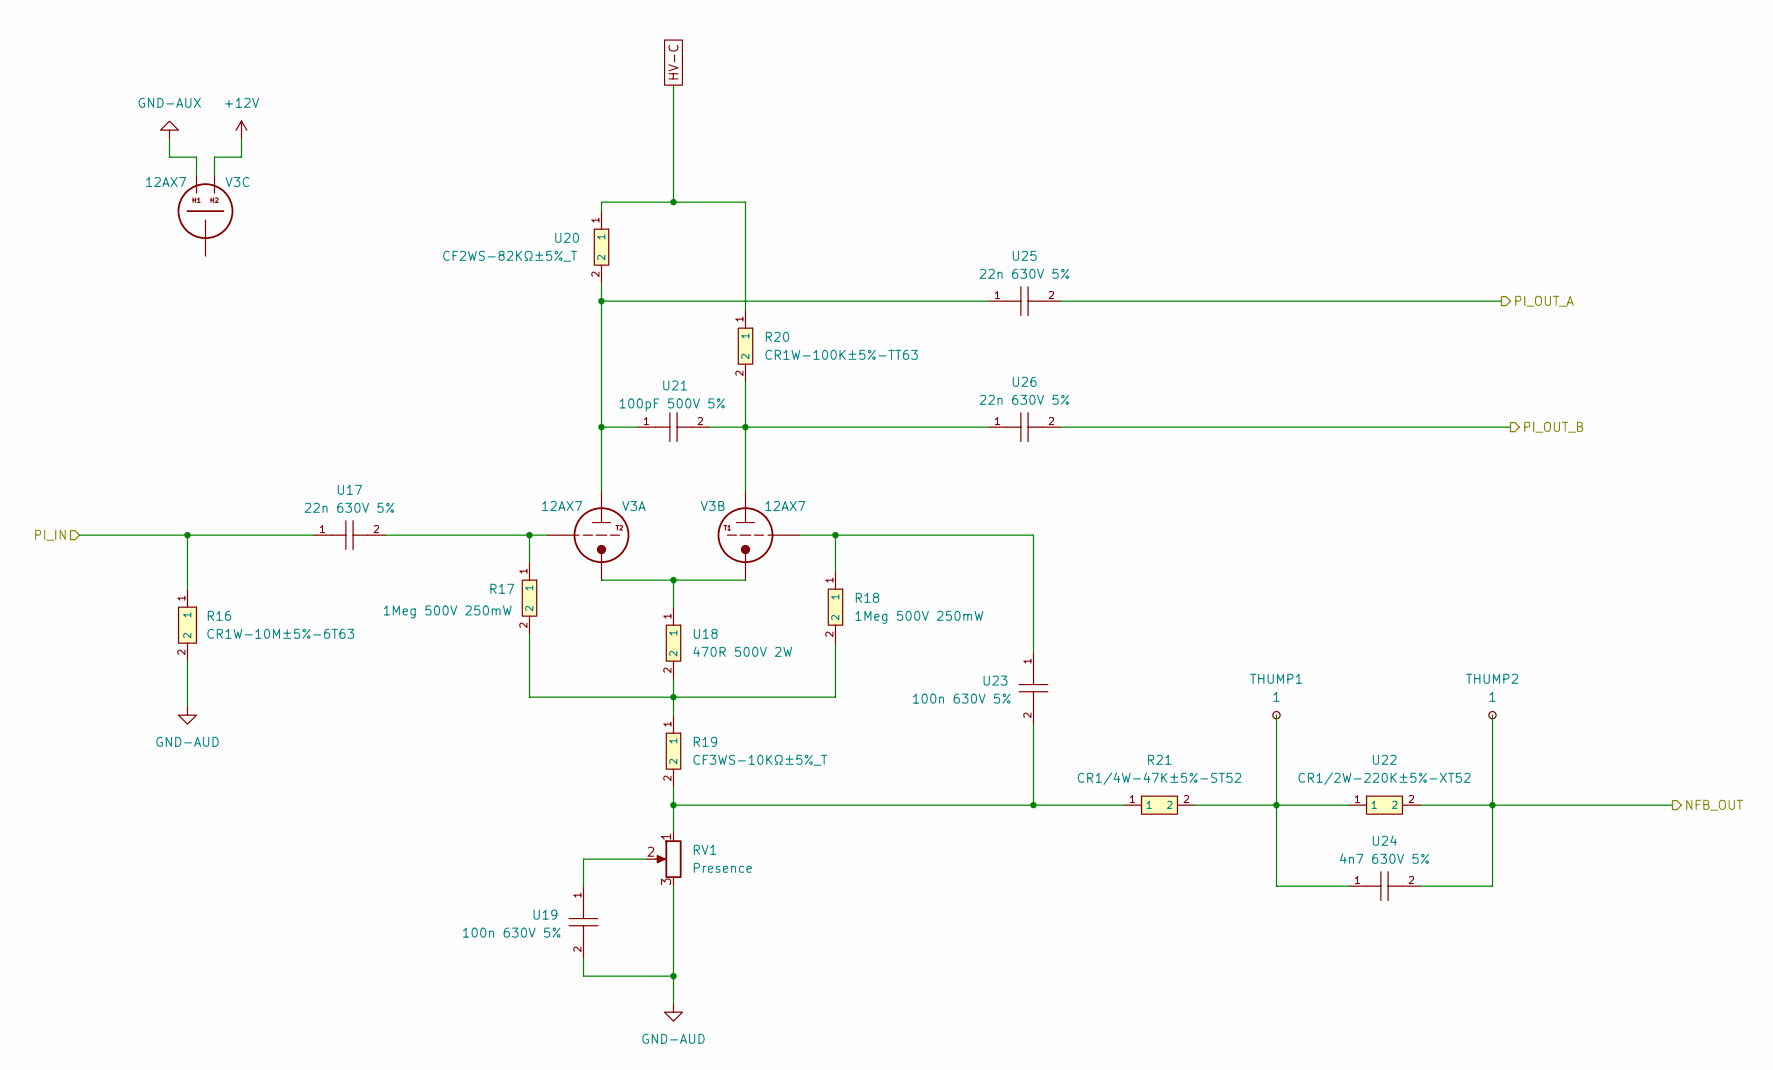
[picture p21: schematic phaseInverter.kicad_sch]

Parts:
R16: CR1W-10M±5%-6T63; RES-TH_BD4.5-L11.0-P15.00-D0.7; LCSC C2897121
R17, R18: 1Meg 500V 250mW; RES-TH_BD2.4-L6.3-P10.30-D0.6; LCSC C1370556
R19: CF3WS-10KΩ±5%_T; RES-TH_BD5.5-L15.0-P19.00-D0.8; LCSC C120810
R20: CR1W-100K±5%-TT63; RES-TH_BD4.5-L11.0-P15.00-D0.7; LCSC C601829
R21: CR1/4W-47K±5%-ST52; RES-TH_BD2.7-L6.2-P10.20-D0.4; LCSC C2896823
RV1: Presence; WB50_Pot_Omeg_PC20BU_P5.00mm
THUMP1, THUMP2: 1; TestPoint_THTPad_D3.0mm_Drill1.5mm
U17, U25, U26: 22n 630V 5%; MUSTARD_CAP_D8.5_L20.5_P25.5
U18: 470R 500V 2W; RES-TH_BD5.0-L15.5-P19.50-D0.7; LCSC C2905226
U19, U23: 100n 630V 5%; MUSTARD_CAP_D10_L32_P40.4
U20: CF2WS-82KΩ±5%_T; RES-TH_BD4.0-L11.5-P15.50-D0.7; LCSC C120647
U21: 100pF 500V 5%; MICA_CAP_L15.5_W3.6_P8.7
U22: CR1/2W-220K±5%-XT52; RES-TH_BD3.5-L9.0-P13.00-D0.5; LCSC C2894491
U24: 4n7 630V 5%; MUSTARD_CAP_D8.5_L20.5_P25.5
V3: 12AX7; WB50_Socket_Noval_9Pin_D21.0mm_Hole1.8mm

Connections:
+12V: V3.4 (H1); also elsewhere on the board
/Connectors/NFB_IN: THUMP2.1, U22.2, U24.2; also elsewhere on the board
/Phase Inverter/PI_IN: R16.1, U17.1; also elsewhere on the board
/Phase Inverter/PI_OUT_A: U25.2; also elsewhere on the board
/Phase Inverter/PI_OUT_B: U26.2; also elsewhere on the board
GND-AUD: R16.2, RV1.3, U19.2; also elsewhere on the board
GND-AUX: V3.5 (H2); also elsewhere on the board
HV-C: R20.1, U20.1; also elsewhere on the board
unnamed: R17.2, R18.2, R19.1, U18.2
unnamed: R19.2, R21.1, RV1.1, U23.2
unnamed: R21.2, THUMP1.1, U22.1, U24.1
unnamed: RV1.2, U19.1
unnamed: U20.2, U21.1, U25.1, V3.1 (A/P)
unnamed: U18.1, V3.3 (C/K), V3.8 (C/K)
unnamed: R17.1, U17.2, V3.2 (G)
unnamed: R20.2, U21.2, U26.1, V3.6 (A/P)
unnamed: R18.1, U23.1, V3.7 (G)

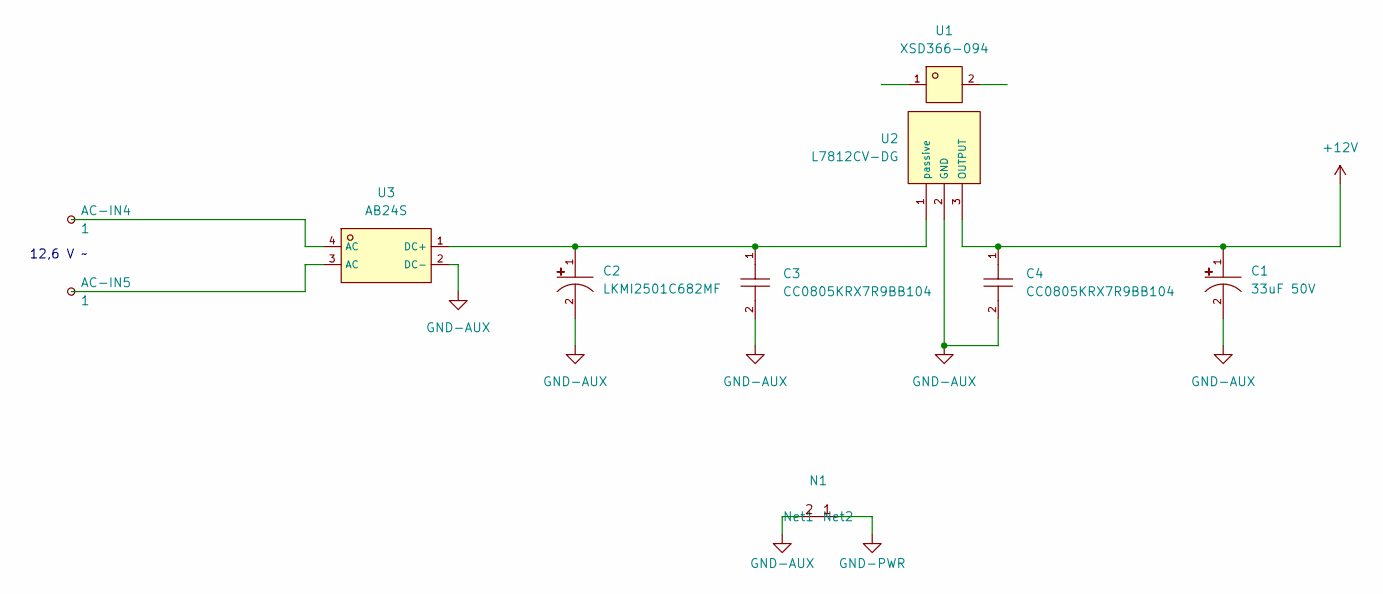
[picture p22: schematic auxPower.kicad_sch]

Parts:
AC-IN4, AC-IN5: 1; TestPoint_THTPad_D3.0mm_Drill1.5mm
C1: 33uF 50V; CAP-TH_BD5.0-P2.00-D0.8-FD; LCSC C89792
C2: LKMI2501C682MF; CAP-TH_BD16.0-P7.50-D1.2-FD; LCSC C442803
C3, C4: CC0805KRX7R9BB104; C0805; LCSC C49678
N1: NetTie_0.5mm_2Pad
U1: XSD366-094; HEATSINK-TH_XSD366-094; LCSC C286227
U2: L7812CV-DG; TO-220-3_L10.0-W4.5-P2.54-L; LCSC C2914
U3: AB24S; ABS-SMD_L5.0-W4.4-P4.00-LS7.0-BL; LCSC C882375

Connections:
+12V: C1.1, C4.1, U2.3 (OUTPUT); also elsewhere on the board
GND-AUX: C1.2, C2.2, C3.2, C4.2, N1.2 (Net2), U2.2 (GND), U3.2 (DC-); also elsewhere on the board
GND-PWR: N1.1 (Net1); also elsewhere on the board
unnamed: AC-IN4.1, U3.4 (AC)
unnamed: AC-IN5.1, U3.3 (AC)
unnamed: C2.1, C3.1, U2.1 (passive), U3.1 (DC+)

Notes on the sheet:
12,6 V ~

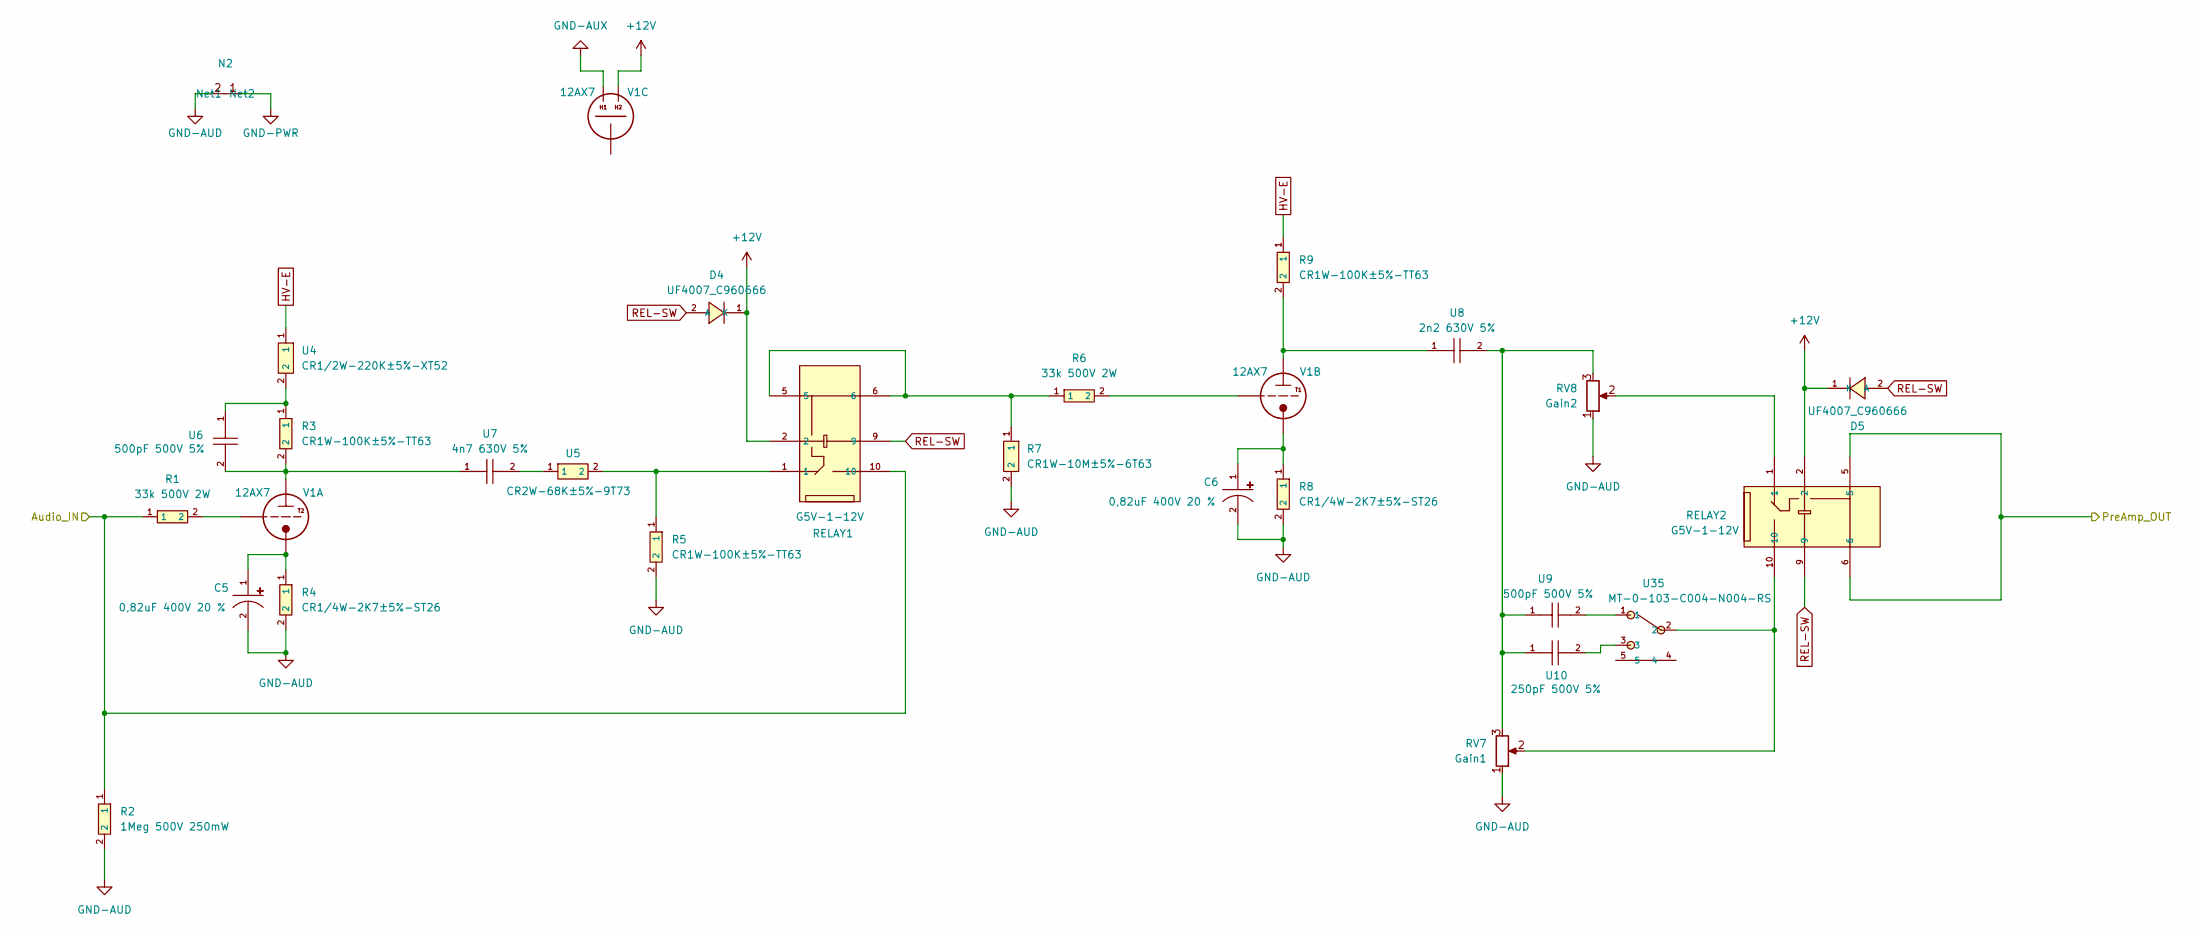
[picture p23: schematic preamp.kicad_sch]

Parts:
C5, C6: 0,82uF 400V 20 %; CAP-TH_BD6.3-P2.50-D1.0-FD; LCSC C2029
D4, D5: UF4007_C960666; DO-41_BD2.4-L4.7-P8.70-D0.9-RD; LCSC C960666
N2: NetTie_0.5mm_2Pad
R1, R6: 33k 500V 2W; RES-TH_BD3.0-L9.5-P13.50-D0.6; LCSC C70845
R2: 1Meg 500V 250mW; RES-TH_BD2.4-L6.3-P10.30-D0.6; LCSC C1370556
R3, R5, R9: CR1W-100K±5%-TT63; RES-TH_BD4.5-L11.0-P15.00-D0.7; LCSC C601829
R4, R8: CR1/4W-2K7±5%-ST26; RES-TH_BD2.7-L6.2-P10.20-D0.4; LCSC C2894624
R7: CR1W-10M±5%-6T63; RES-TH_BD4.5-L11.0-P15.00-D0.7; LCSC C2897121
RELAY1, RELAY2: G5V-1-12V; RELAY-TH_G5V-1; LCSC C31113
RV7: Gain1; WB50_Pot_Omeg_PC20BU_P5.00mm
RV8: Gain2; WB50_Pot_Omeg_PC20BU_P5.00mm
U4: CR1/2W-220K±5%-XT52; RES-TH_BD3.5-L9.0-P13.00-D0.5; LCSC C2894491
U5: CR2W-68K±5%-9T73; RES-TH_BD5.0-L15.5-P19.50-D0.7; LCSC C2903458
U6, U9: 500pF 500V 5%; MICA_CAP_L15.5_W3.6_P8.7
U7: 4n7 630V 5%; MUSTARD_CAP_D8.5_L20.5_P25.5
U8: 2n2 630V 5%; MUSTARD_CAP_D8.5_L20.5_P25.5
U10: 250pF 500V 5%; MICA_CAP_L15.5_W3.6_P8.7
U35: MT-0-103-C004-N004-RS; SW-TH_MT-0-102-C004-N004-RS; LCSC C22448931
V1: 12AX7; WB50_Socket_Noval_9Pin_D21.0mm_Hole1.8mm

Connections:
+12V: D4.1 (K), D5.1 (K), RELAY1.2, RELAY2.2, V1.4 (H1); also elsewhere on the board
/Connectors/Audio_IN: R1.1, R2.1, RELAY1.10; also elsewhere on the board
/Pre Amp/PreAmp_OUT: RELAY2.5, RELAY2.6; also elsewhere on the board
GND-AUD: C5.2, C6.2, N2.2 (Net2), R2.2, R4.2, R5.2, R7.2, R8.2, RV7.1, RV8.1; also elsewhere on the board
GND-AUX: V1.5 (H2); also elsewhere on the board
GND-PWR: N2.1 (Net1); also elsewhere on the board
HV-E: R9.1, U4.1; also elsewhere on the board
unnamed: R3.1, U4.2, U6.1
unnamed: R5.1, RELAY1.1, U5.2
unnamed: R6.1, R7.1, RELAY1.5, RELAY1.6
unnamed: RELAY2.1, RV8.2
unnamed: RELAY2.10, RV7.2, U35.2
unnamed: RV7.3, RV8.3, U8.2, U9.1, U10.1
unnamed: U5.1, U7.2
unnamed: U10.2, U35.3
unnamed: U9.2, U35.1
unnamed: R3.2, U6.2, U7.1, V1.1 (A/P)
unnamed: C5.1, R4.1, V1.3 (C/K)
unnamed: R1.2, V1.2 (G)
unnamed: R9.2, U8.1, V1.6 (A/P)
unnamed: C6.1, R8.1, V1.8 (C/K)
unnamed: R6.2, V1.7 (G)
REL-SW: D4.2 (A), D5.2 (A), RELAY1.9, RELAY2.9; also elsewhere on the board

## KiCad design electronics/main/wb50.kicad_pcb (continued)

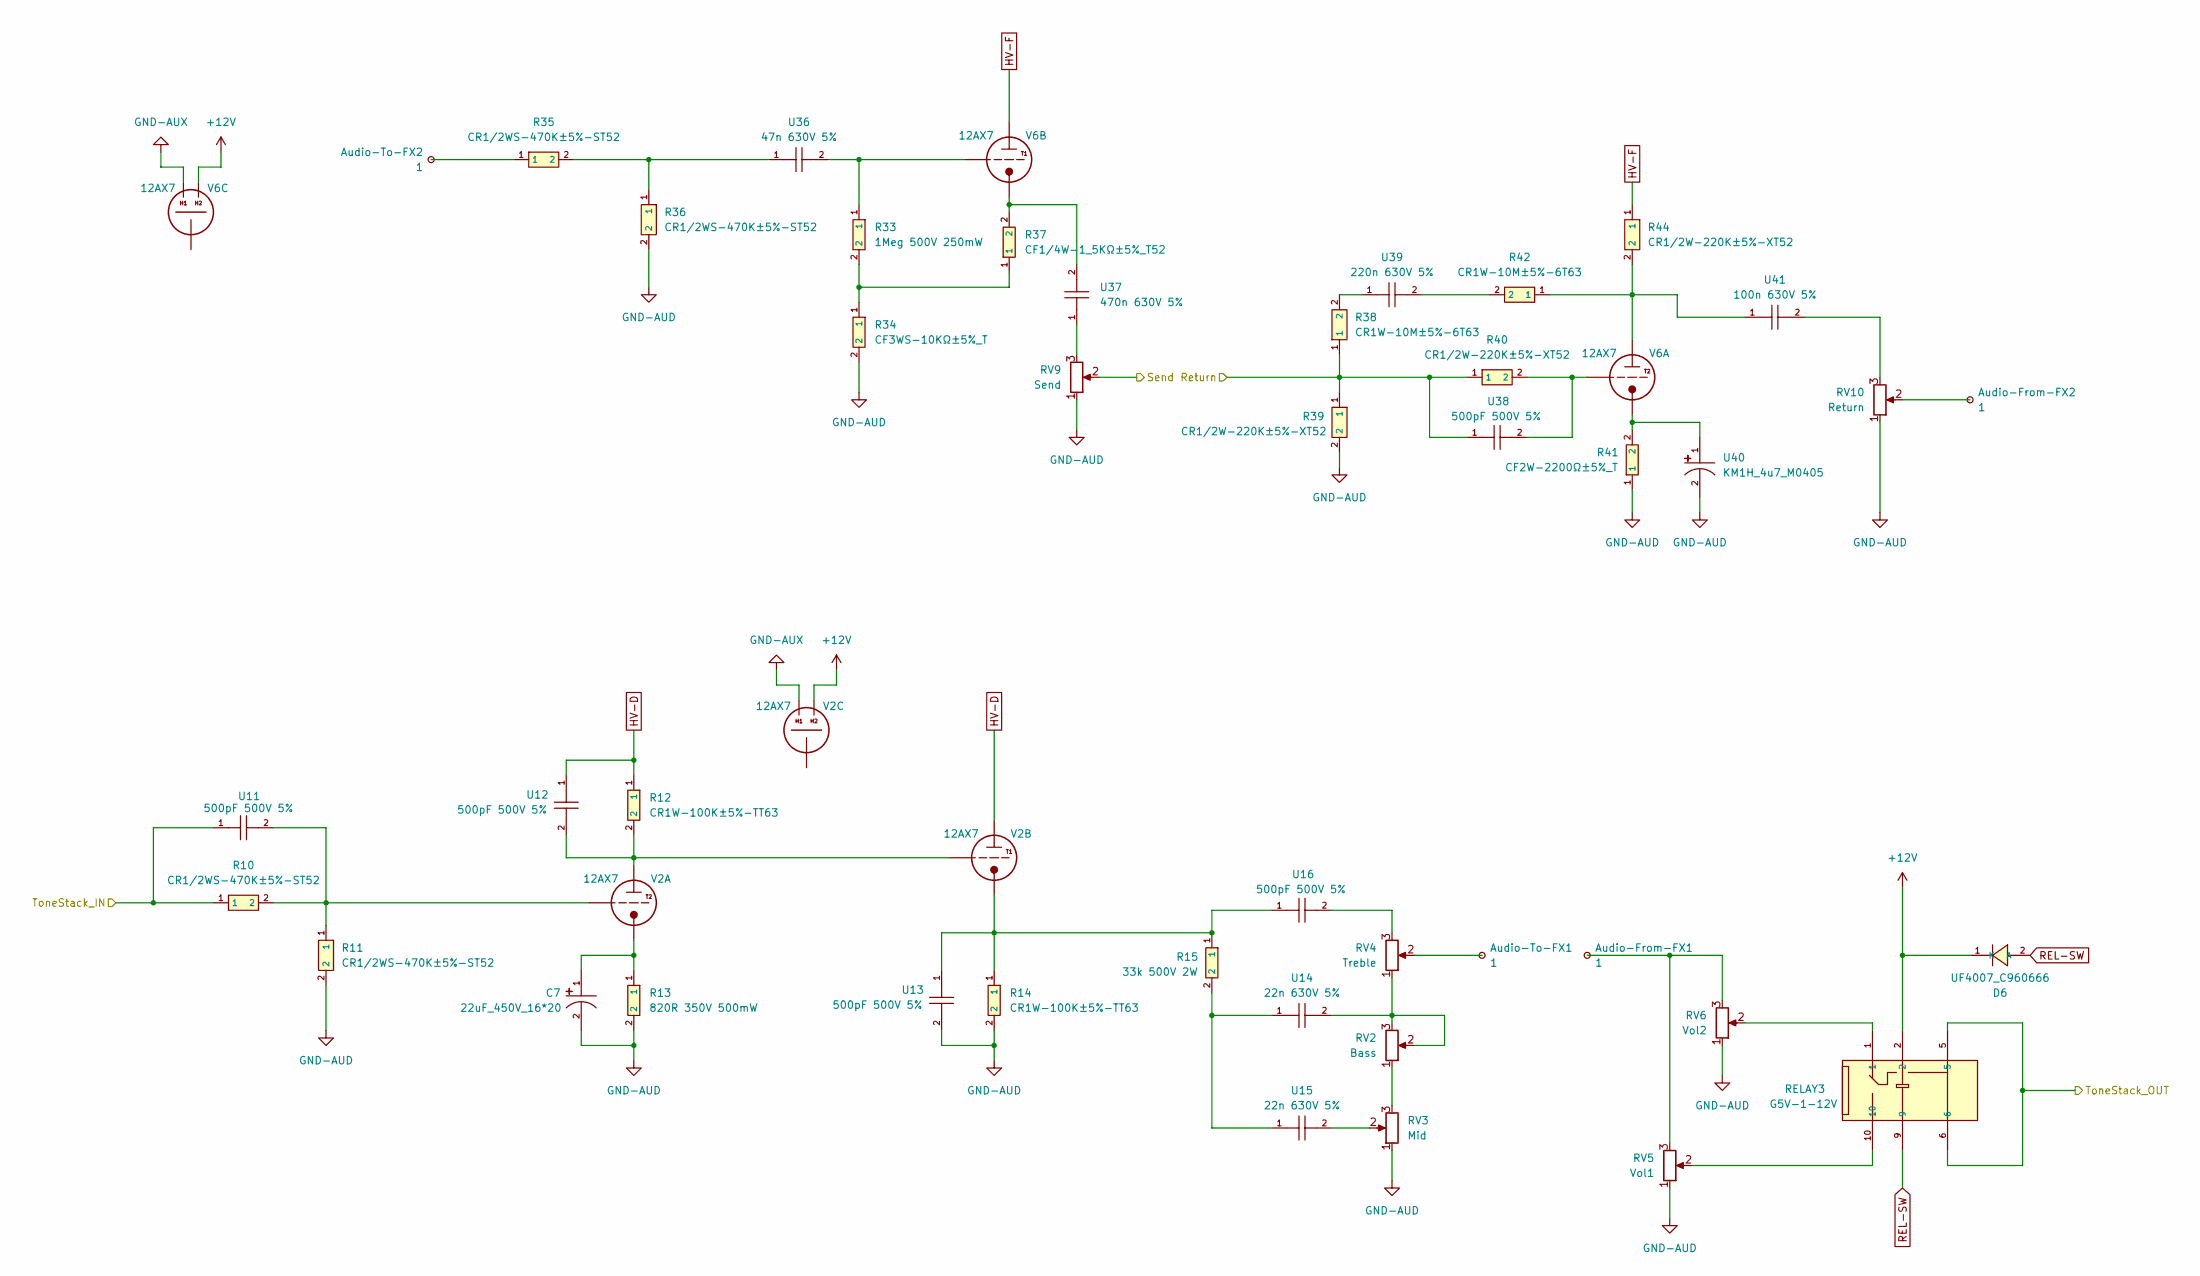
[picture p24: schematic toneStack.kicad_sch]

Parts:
Audio-From-FX1, Audio-From-FX2: 1; TestPoint_THTPad_D3.0mm_Drill1.5mm
Audio-To-FX1, Audio-To-FX2: 1; TestPoint_THTPad_D3.0mm_Drill1.5mm
C7: 22uF_450V_16*20; CAP-TH_BD16.0-P7.50-D1.2-FD; LCSC C10737
D6: UF4007_C960666; DO-41_BD2.4-L4.7-P8.70-D0.9-RD; LCSC C960666
R10, R11, R35, R36: CR1/2WS-470K±5%-ST52; RES-TH_BD2.7-L6.2-P10.20-D0.4; LCSC C2857409
R12, R14: CR1W-100K±5%-TT63; RES-TH_BD4.5-L11.0-P15.00-D0.7; LCSC C601829
R13: 820R 350V 500mW; RES-TH_BD4.0-L10.5-P14.50-D0.6; LCSC C167619
R15: 33k 500V 2W; RES-TH_BD3.0-L9.5-P13.50-D0.6; LCSC C70845
R33: 1Meg 500V 250mW; RES-TH_BD2.4-L6.3-P10.30-D0.6; LCSC C1370556
R34: CF3WS-10KΩ±5%_T; RES-TH_BD5.5-L15.0-P19.00-D0.8; LCSC C120810
R37: CF1/4W-1_5KΩ±5%_T52; RES-TH_BD2.3-L6.5-P10.50-D0.5; LCSC C120059
R38, R42: CR1W-10M±5%-6T63; RES-TH_BD4.5-L11.0-P15.00-D0.7; LCSC C2897121
R39, R40, R44: CR1/2W-220K±5%-XT52; RES-TH_BD3.5-L9.0-P13.00-D0.5; LCSC C2894491
R41: CF2W-2200Ω±5%_T; RES-TH_BD5.5-L15.0-P19.00-D0.8; LCSC C187501
RELAY3: G5V-1-12V; RELAY-TH_G5V-1; LCSC C31113
RV2: Bass; WB50_Pot_Omeg_PC20BU_P5.00mm
RV3: Mid; WB50_Pot_Omeg_PC20BU_P5.00mm
RV4: Treble; WB50_Pot_Omeg_PC20BU_P5.00mm
RV5: Vol1; WB50_Pot_Omeg_PC20BU_P5.00mm
RV6: Vol2; WB50_Pot_Omeg_PC20BU_P5.00mm
RV9: Send; WB50_Pot_Omeg_PC20BU_P5.00mm
RV10: Return; WB50_Pot_Omeg_PC20BU_P5.00mm
U11, U12, U13, U16, U38: 500pF 500V 5%; MICA_CAP_L15.5_W3.6_P8.7
U14, U15: 22n 630V 5%; MUSTARD_CAP_D8.5_L20.5_P25.5
U36: 47n 630V 5%; MUSTARD_CAP_D8.5_L20.5_P25.5
U37: 470n 630V 5%; MUSTARD_CAP_D10_L32_P40.4
U39: 220n 630V 5%; MUSTARD_CAP_D10_L32_P40.4
U40: KM1H_4u7_M0405; CAP-TH_BD4.0-P1.50-D0.5-FD; LCSC C2873979
U41: 100n 630V 5%; MUSTARD_CAP_D10_L32_P40.4
V2, V6: 12AX7; WB50_Socket_Noval_9Pin_D21.0mm_Hole1.8mm

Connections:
+12V: D6.1 (K), RELAY3.2, V2.4 (H1), V6.4 (H1); also elsewhere on the board
/Connectors/Return: R38.1, R39.1, R40.1, U38.1; also elsewhere on the board
/Connectors/Send: RV9.2; also elsewhere on the board
/Phase Inverter/PI_IN: RELAY3.5, RELAY3.6; also elsewhere on the board
/Pre Amp/PreAmp_OUT: R10.1, U11.1; also elsewhere on the board
GND-AUD: C7.2, R11.2, R13.2, R14.2, R34.2, R36.2, R39.2, R41.1, RV3.1, RV5.1, RV6.1, RV9.1, RV10.1, U13.2, U40.2; also elsewhere on the board
GND-AUX: V2.5 (H2), V6.5 (H2); also elsewhere on the board
HV-D: R12.1, U12.1, V2.6 (A/P); also elsewhere on the board
HV-F: R44.1, V6.6 (A/P); also elsewhere on the board
unnamed: Audio-From-FX1.1, RV5.3, RV6.3
unnamed: Audio-From-FX2.1, RV10.2
unnamed: Audio-To-FX1.1, RV4.2
unnamed: Audio-To-FX2.1, R35.1
unnamed: R15.2, U14.1, U15.1
unnamed: R33.2, R34.1, R37.1
unnamed: R35.2, R36.1, U36.1
unnamed: R38.2, U39.1
unnamed: R42.2, U39.2
unnamed: RELAY3.1, RV6.2
unnamed: RELAY3.10, RV5.2
unnamed: RV2.1, RV3.3
unnamed: RV2.2, RV2.3, RV4.1, U14.2
unnamed: RV3.2, U15.2
unnamed: RV4.3, U16.2
unnamed: RV9.3, U37.1
unnamed: RV10.3, U41.2
unnamed: R12.2, U12.2, V2.1 (A/P), V2.7 (G)
unnamed: C7.1, R13.1, V2.3 (C/K)
unnamed: R10.2, R11.1, U11.2, V2.2 (G)
unnamed: R14.1, R15.1, U13.1, U16.1, V2.8 (C/K)
unnamed: R42.1, R44.2, U41.1, V6.1 (A/P)
unnamed: R41.2, U40.1, V6.3 (C/K)
unnamed: R40.2, U38.2, V6.2 (G)
unnamed: R37.2, U37.2, V6.8 (C/K)
unnamed: R33.1, U36.2, V6.7 (G)
REL-SW: D6.2 (A), RELAY3.9; also elsewhere on the board

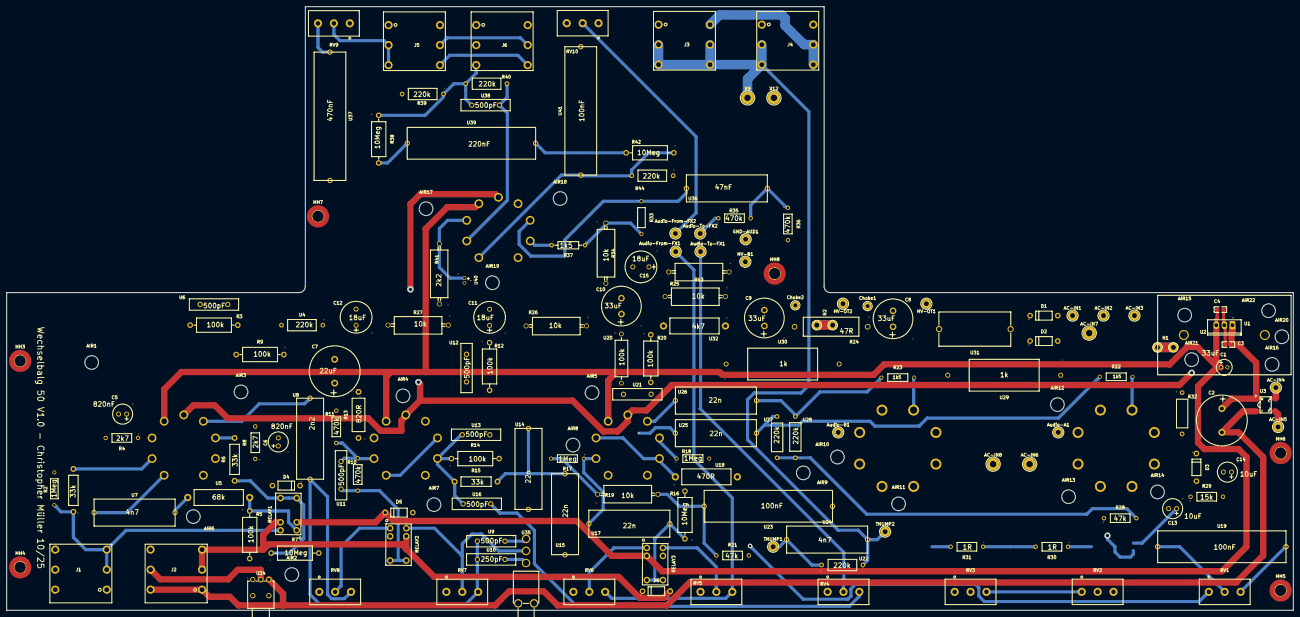
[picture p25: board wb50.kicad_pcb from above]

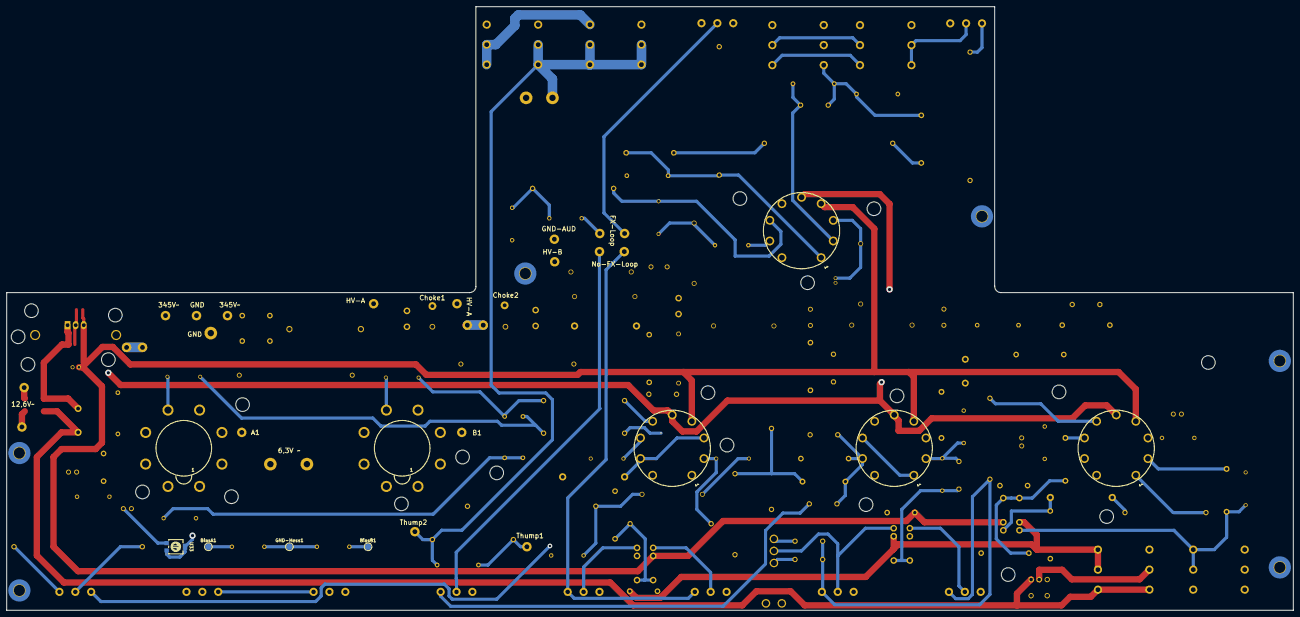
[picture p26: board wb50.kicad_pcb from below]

Board: 4 copper layers, 405.0 x 190.0 mm, 188 parts (10 on the bottom side), 94 nets.

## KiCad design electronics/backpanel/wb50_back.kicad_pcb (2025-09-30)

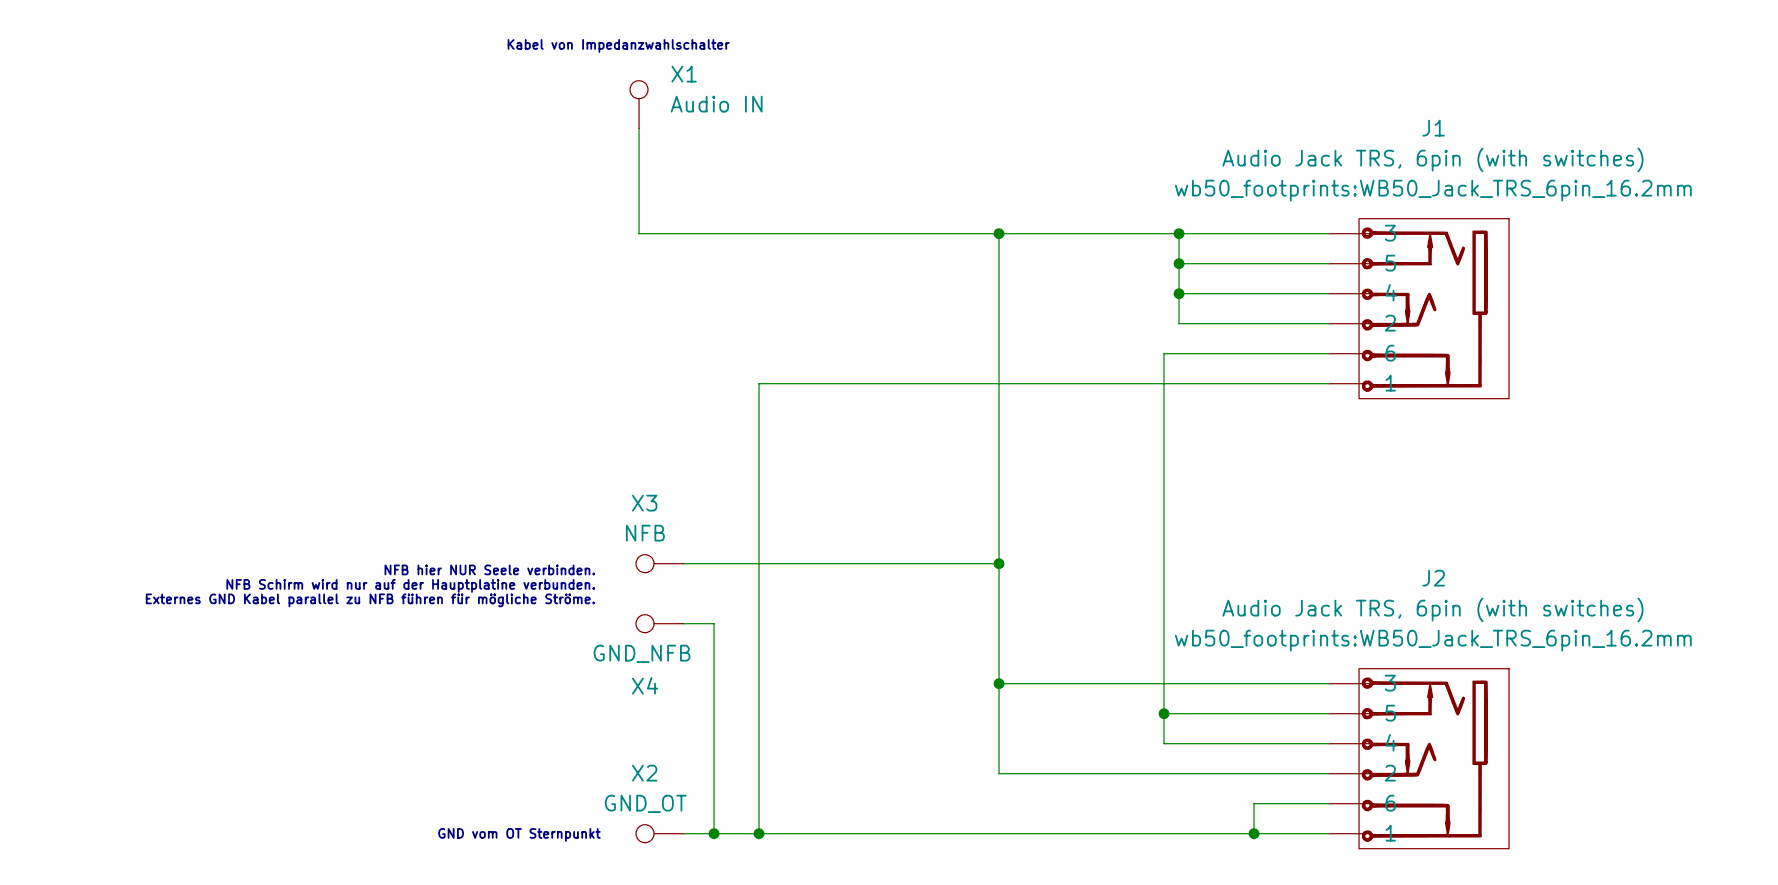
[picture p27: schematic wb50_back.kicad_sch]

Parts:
J1, J2: Audio Jack TRS, 6pin (with switches); WB50_Jack_TRS_6pin_16.2mm
X1: Audio IN; TestPoint_THTPad_D4.0mm_Drill2.0mm
X2: GND_OT; TestPoint_THTPad_D4.0mm_Drill2.0mm
X3: NFB; TestPoint_THTPad_D1.5mm_Drill0.7mm
X4: GND_NFB; TestPoint_THTPad_D4.0mm_Drill2.0mm

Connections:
unnamed: J1.1, J2.1, J2.6, X2.1, X4.1
unnamed: J1.2, J1.3, J1.4, J1.5, J2.2, J2.3, X1.1, X3.1
unnamed: J1.6, J2.4, J2.5

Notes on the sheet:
Kabel von Impedanzwahlschalter
NFB hier NUR Seele verbinden. NFB Schirm wird nur auf der Hauptplatine verbunden. Externes GND Kabel parallel zu NFB führen für mögliche Ströme.
GND vom OT Sternpunkt

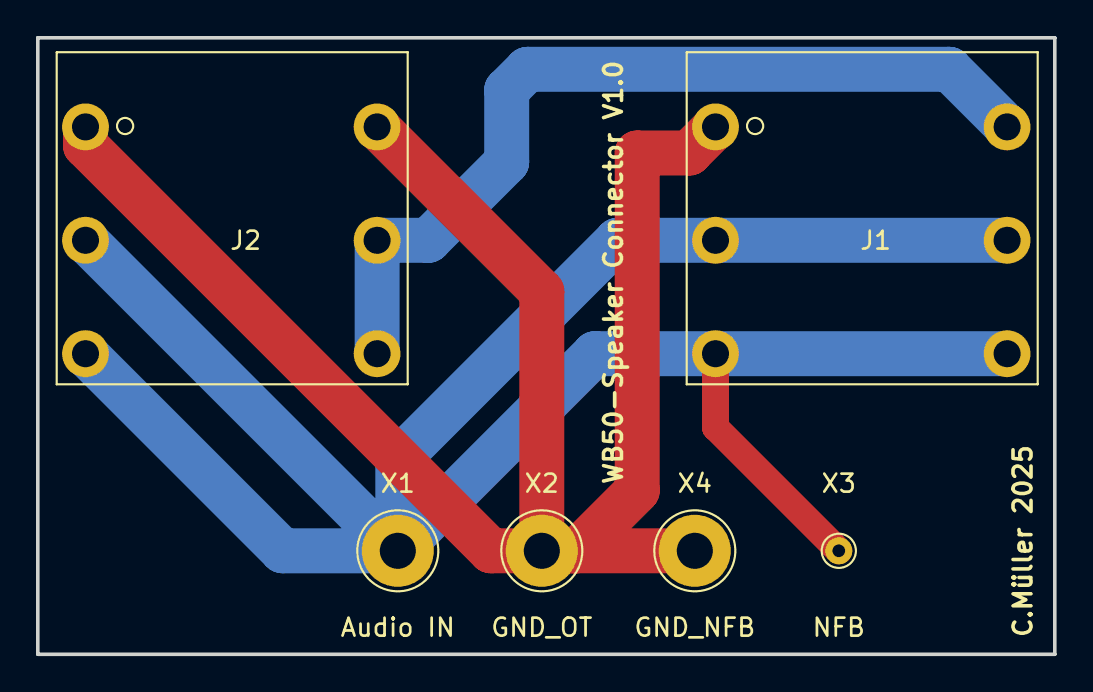
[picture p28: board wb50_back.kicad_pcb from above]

Board: 2 copper layers, 56.5 x 34.2 mm, 6 parts (0 on the bottom side), 3 nets.

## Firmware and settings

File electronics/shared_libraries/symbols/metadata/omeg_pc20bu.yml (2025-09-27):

# Omeg PC20BU Potentiometer metadata for KiCad symbol fields
manufacturer: Omeg
mpn: PC20BU
series: P20
family: PC20
track_material: Conductive polymer (plastic)
rotation_total: "300 ±5 deg"
rotation_effective: "256 deg nominal"
operating_torque_cNm: "0.4 – 1.5"
endstop_torque_cNm: 80
axial_spindle_load_N: 100
axial_spindle_load_note: "5 s max"
law_power_rating_40C:
  linear_W: 0.4
  nonlinear_W: 0.2
options:
  click_stops: optional
  torque_variant: "high or low"
mechanical:
  shaft_diameter_mm: 6
  bushing_thread: "M10 x 0.75"
  body_width_mm: 16
  body_depth_mm: 8
  pin_pitch_mm: 5.0
  pin_plane_offset_from_bushing_mm: 6.5
footprint_default: wb50_footprints:WB50_Pot_Omeg_PC20BU_P5.00mm
model_3d_default: "${KIPRJMOD}/libraries/3dmodels/PC20BU.stp"
notes: |
  - Rated power depends on law: 0.4 W (linear), 0.2 W (nonlinear) @40°C.
  - Conductive polymer track: longer life than carbon tracks.
  - Configure LAW and RESISTANCE per instance (e.g., A100k, B100k).
  - Consider panel reference at +6.5 mm from pin plane for PCB-to-panel alignment.

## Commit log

2025-09-26 Revise README for Wechselbalg 50 amplifier
    Expanded the README to provide detailed information about the Wechselbalg 50 amplifier, including highlights, circuit overview, safety precautions, and project scope.
2025-09-27 KiCad project created and basic setup with basic parts
    [connectors.kicad_sch, controlls.kicad_sch, frontPlate.FCStd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]
2025-09-27 kosten update
    [kosten.csv]
2025-09-27 fonts for front plate
2025-09-27 front plate design
    [frontPlate.FCStd, frontPlate.dxf]
2025-09-28 frontpanel parts placed and locked
    [connectors.kicad_sch, wb50.kicad_pcb]
2025-09-28 bring potentiometers more to front and lock again
    [wb50.kicad_pcb]
2025-09-28 adjust pcb size
    [wb50.kicad_pcb]
2025-09-28 exported step for shield platings
    [wb50.step]
2025-09-28 updated pcb size
    [wb50.kicad_pcb]
2025-09-28 update step with new pcb size
    [wb50.step]
2025-09-29 update cost
    [kosten.csv]
2025-09-30 restructure 2
    [12ax7.STEP, 12ax7andSocket.FCStd, 12ax7andSocket.step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]
2025-09-30 restructure finish
    [wb50.kicad_pcb]
2025-09-30 setup jlcpcb
    [Wand.FCStd, bom.csv, designators.csv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]
2025-09-30 aux voltage
    [Bodenplatte.FCStd, auxPower.kicad_sch, connectors.kicad_sch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]
2025-09-30 update aux voltage
    [auxPower.kicad_sch, wb50.kicad_pcb]
2025-10-01 widerstände angelegt
    [auxPower.kicad_sch, connectors.kicad_sch, preamp.kicad_sch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]
2025-10-03 PI stage ready
    [AXIAL_CYLINDRICAL_FILM_CAPACITOR_D10_L32_Pitch40.4_PinD0.8.step, AXIAL_CYLINDRICAL_FILM_CAPACITOR_D8.5_L20.5_Pitch25.5_PinD0.8.step, Capacitor_Mica_CDV16.step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]
2025-10-05 schematic ready? - check
    [auxPower.kicad_sch, connectors.kicad_sch, kosten.csv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]
2025-10-05 schematic checked!
    [auxPower.kicad_sch, connectors.kicad_sch, phaseInverter.kicad_sch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]
2025-10-08 updated PCB
    [auxPower.kicad_sch, bom.csv, connectors.kicad_sch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]
2025-10-10 update housing, speakers and schematics
    [Bodenplatte.FCStd, Wand.FCStd, auxPower.kicad_sch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]
2025-10-10 update design
    [connectors.kicad_sch, power.kicad_sch, preamp.kicad_sch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]
2025-10-12 add fx loop, add new shield
    [Bodenplatte.FCStd, NIXIE_TUBE.step, bom.csv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]
2025-10-17 update kosten und letzte bestellungen für Teile
    [kosten.csv]
